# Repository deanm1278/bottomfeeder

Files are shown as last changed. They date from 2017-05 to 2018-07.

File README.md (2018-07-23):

# bottomfeeder

demo video of the synthesizer with a control panel added on top is [here](https://youtu.be/Ub5NRgZzTfE).
Note the synthesizer is mounted to the back of the panel in the video.

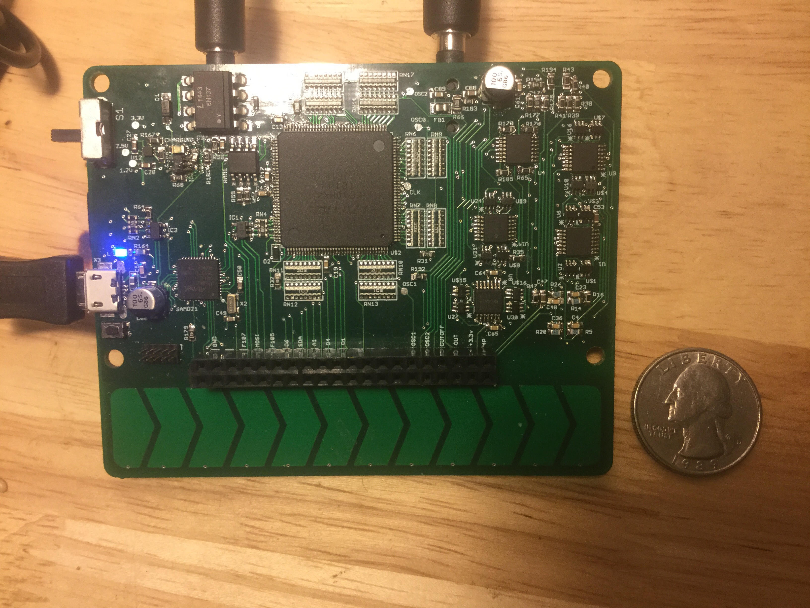
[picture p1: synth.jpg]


Features include:
- 3x 16 bit digital Wavetable Oscillators (sample rates up to 200k samples/sec)
  - Fine and coarse tuning controls for each oscillator
  - user loadable waveforms
  - 1 square wave sub oscillator for each oscillator
- Full analog 4 pole resonant low pass filter
- ADSR envelope generator mappable to filter cutoff and VCA
- Monophonic and 3 voice Paraphonic modes
- Glide rate control
- 2x LFO (also any user loadable waveform)
  - Mappable to many parameters including rate or depth of the other LFO
- Headphone output
- External input to filter
- All parameters controllable via Standard MIDI
- Header connections for modification
- Loading and saving presets
- Low cost and small form factor

## Structure
An ARM Cortex M0+ microcontroller acts as a host processor for an [FPGA-Based synthesizer](https://github.com/deanm1278/Chisel-wavetable).
The FPGA outputs the oscillators as well as PWM control voltages for the analog filter and analog VCA parameters.
[Click here](https://github.com/deanm1278/bottomfeeder/blob/master/schematics/synth_revD.pdf) to view PDF schematics.

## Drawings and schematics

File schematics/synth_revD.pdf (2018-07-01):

10k | AGND ¹⁰⁰k 100k | AGND
R180 | R178 R181 R¹⁸⁴ | R186 | R185 R¹⁸⁷ R188 R¹⁸⁹ R¹⁹⁰

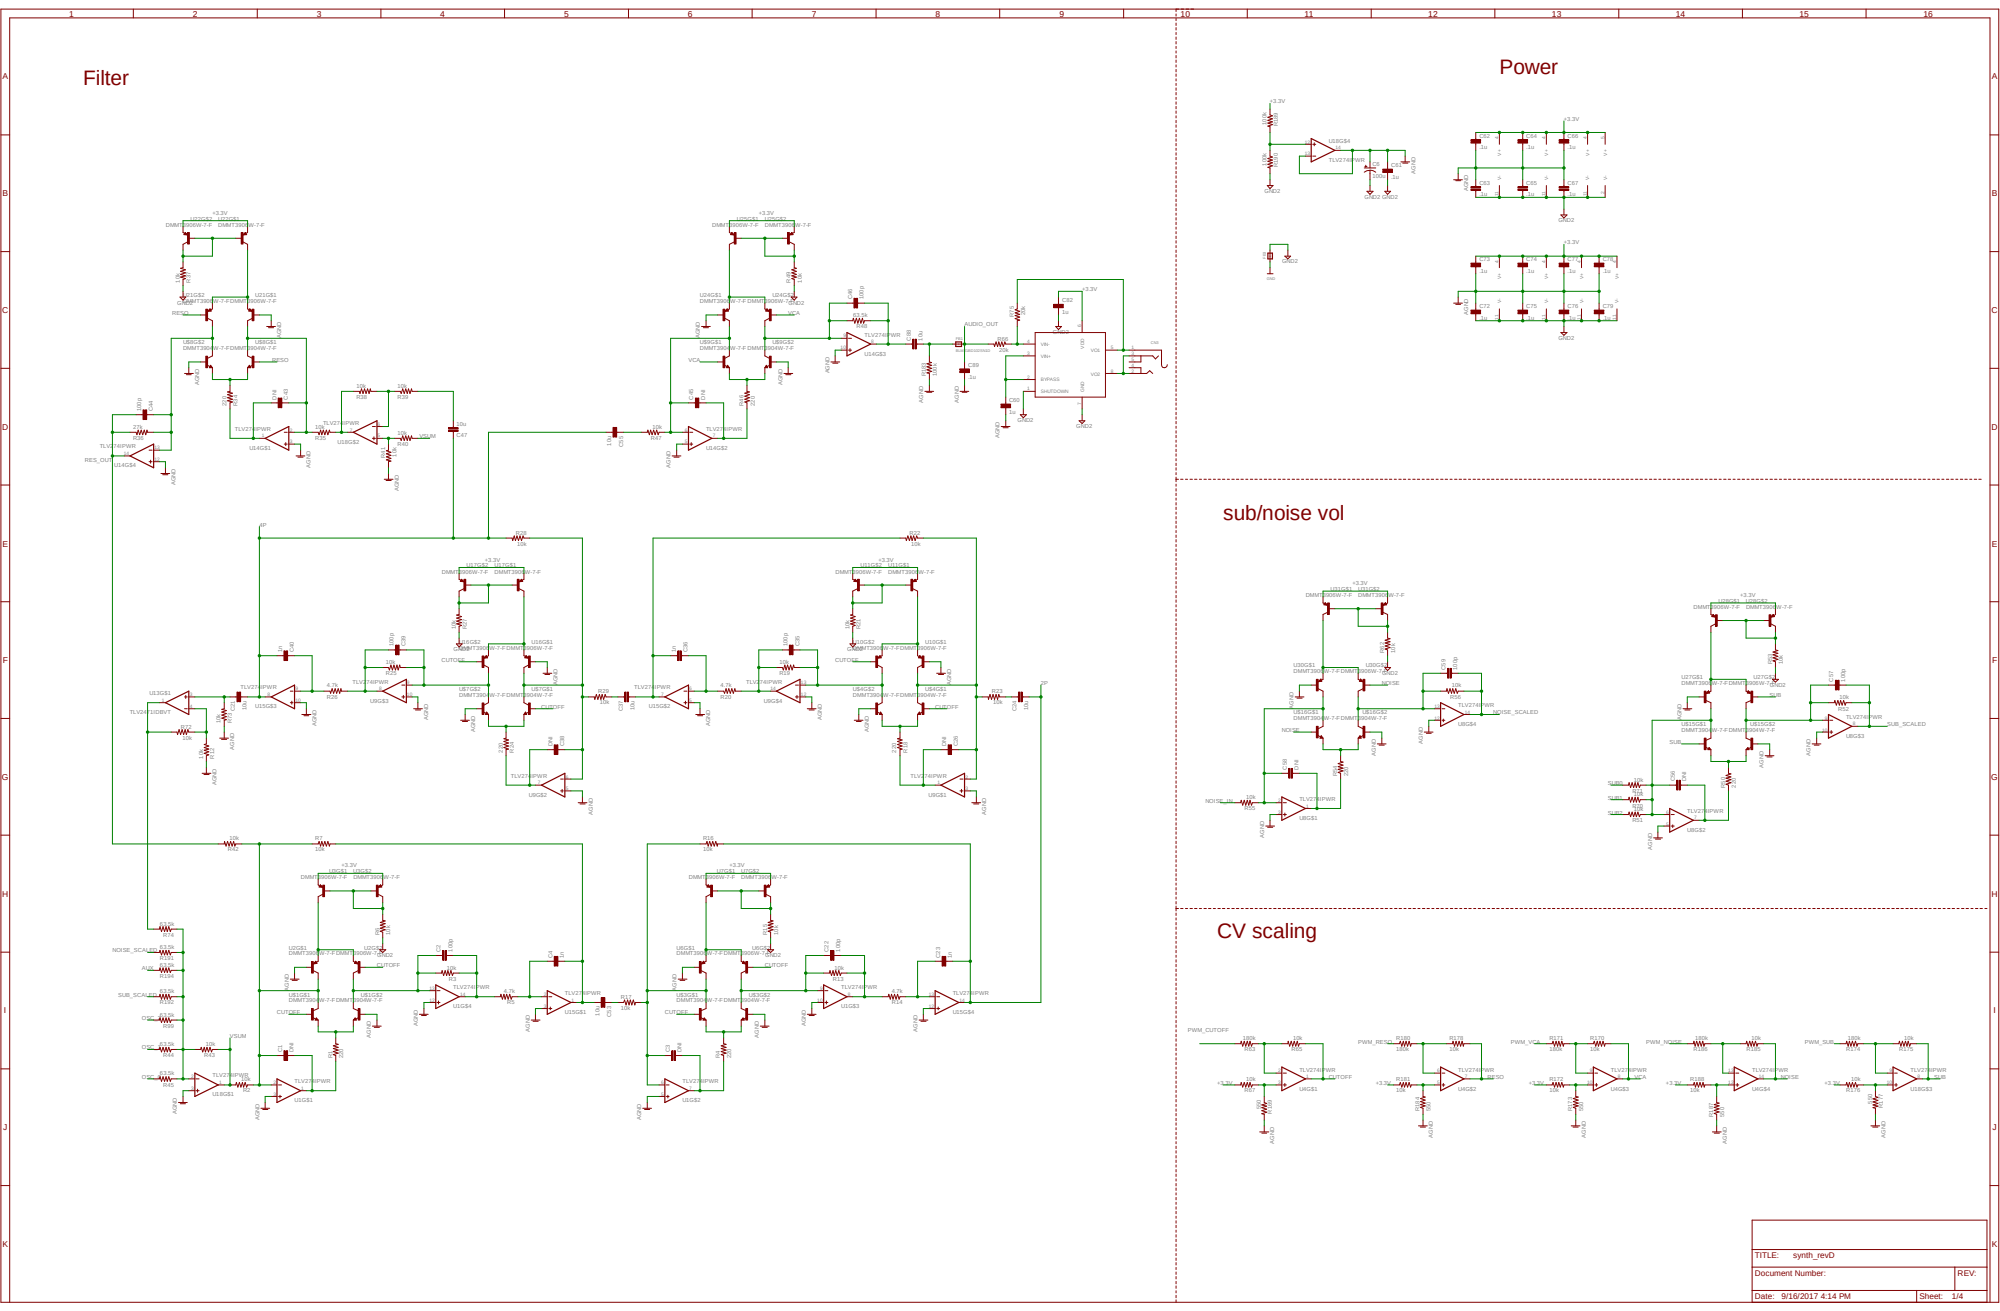
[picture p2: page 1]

IC1 | C41
8 | 9 | RN⁹A¹ ¹⁶RN⁹B² ¹⁵RN⁹C³ ¹⁴RN⁹D⁴ ¹³RN⁹E⁵ ¹²RN⁹F⁶ ¹¹RN⁹G⁷ ¹⁰RN⁹H⁸ ⁹ | RN10A

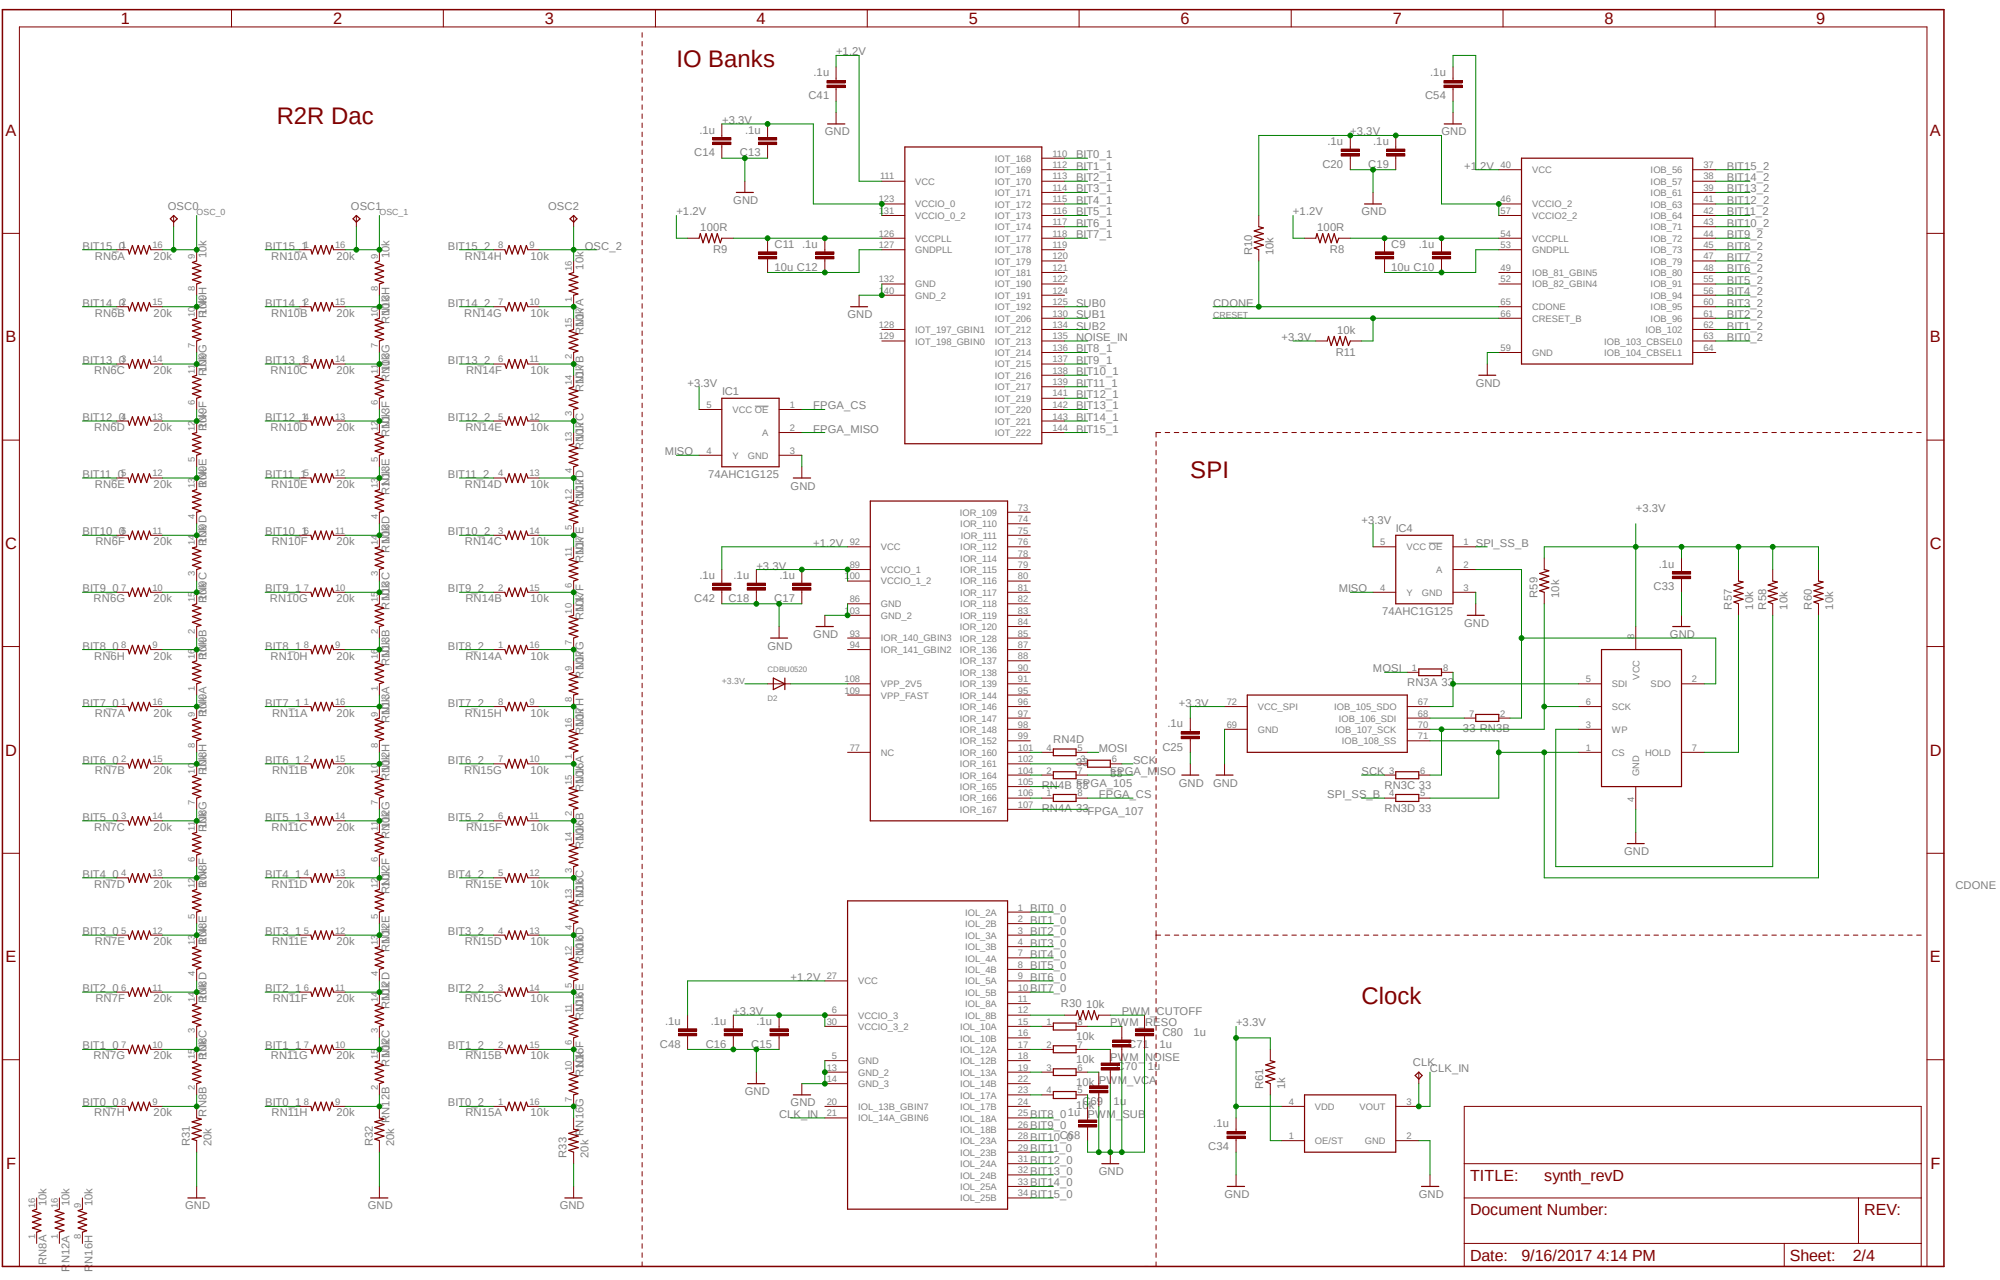
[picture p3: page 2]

# 220 GND 10k 33

# BUTTONS / LEDS

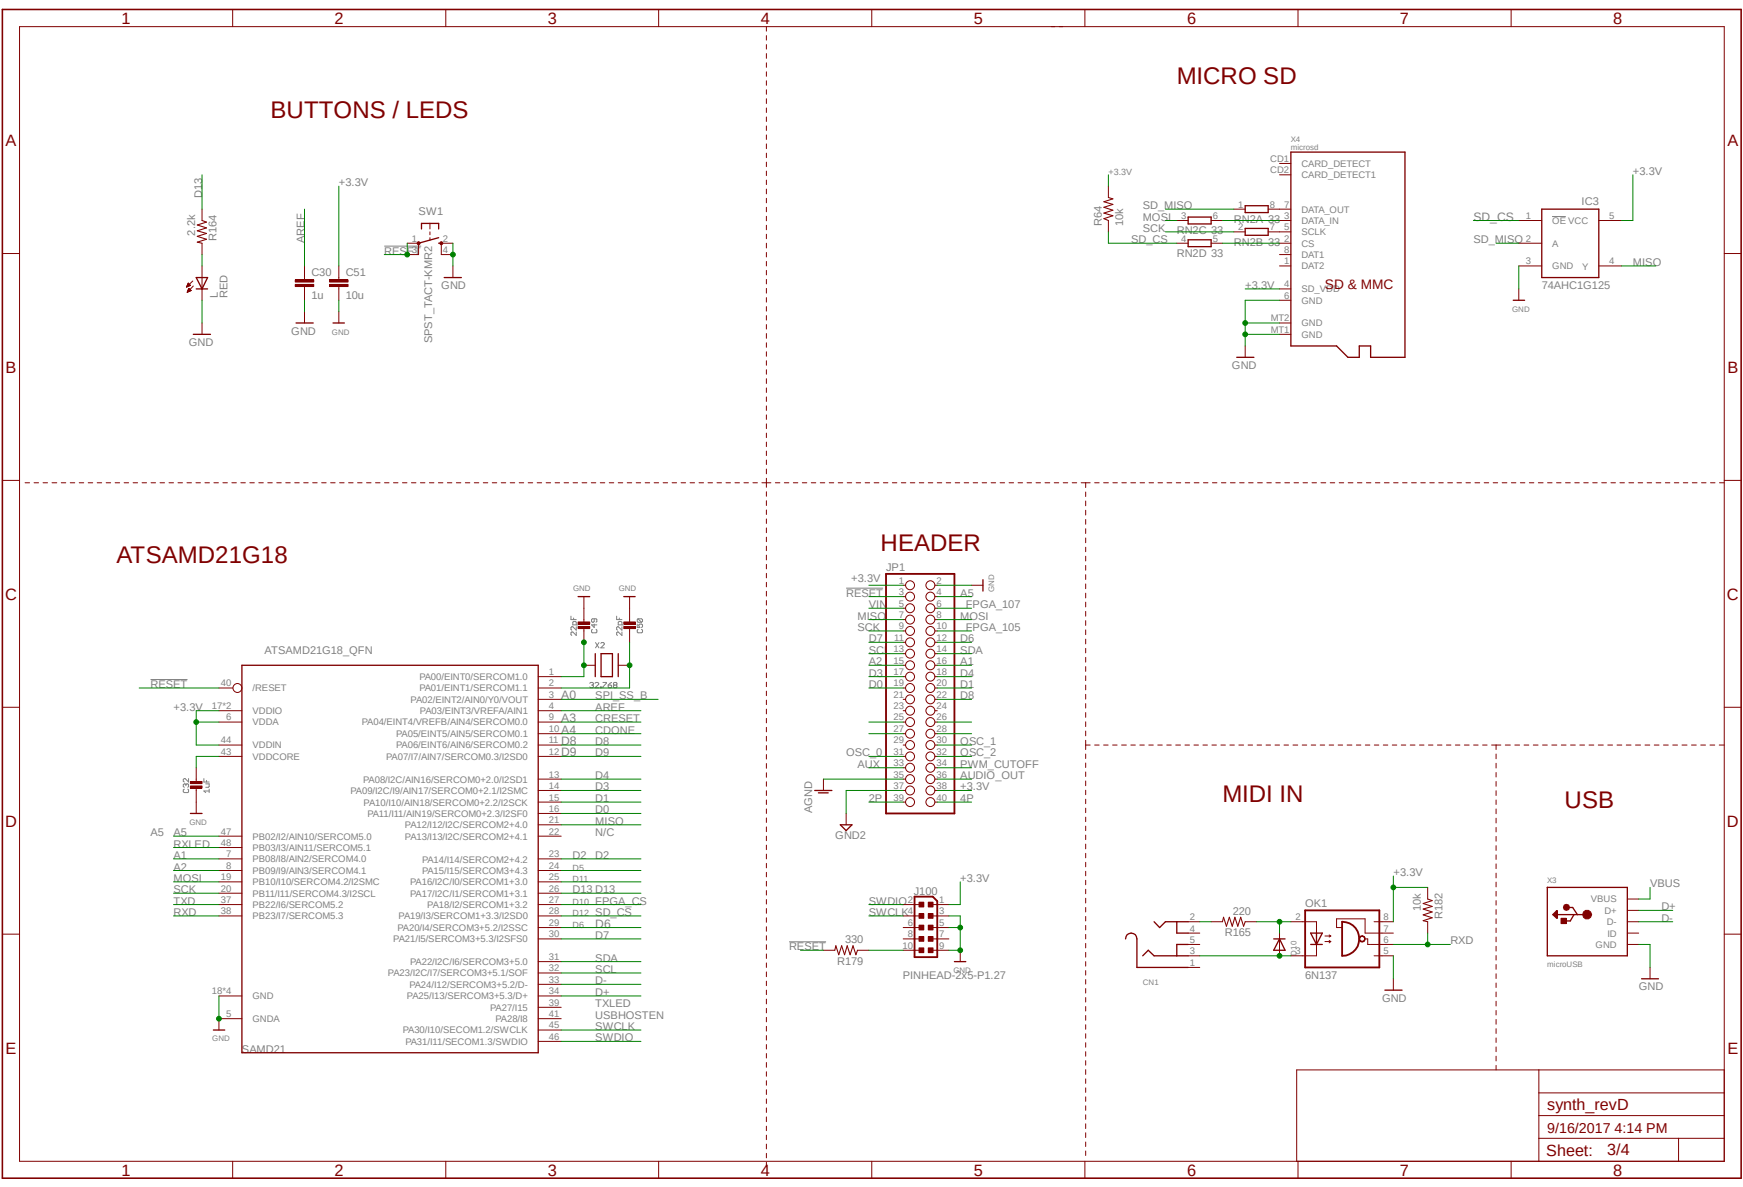
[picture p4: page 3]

CN2

2

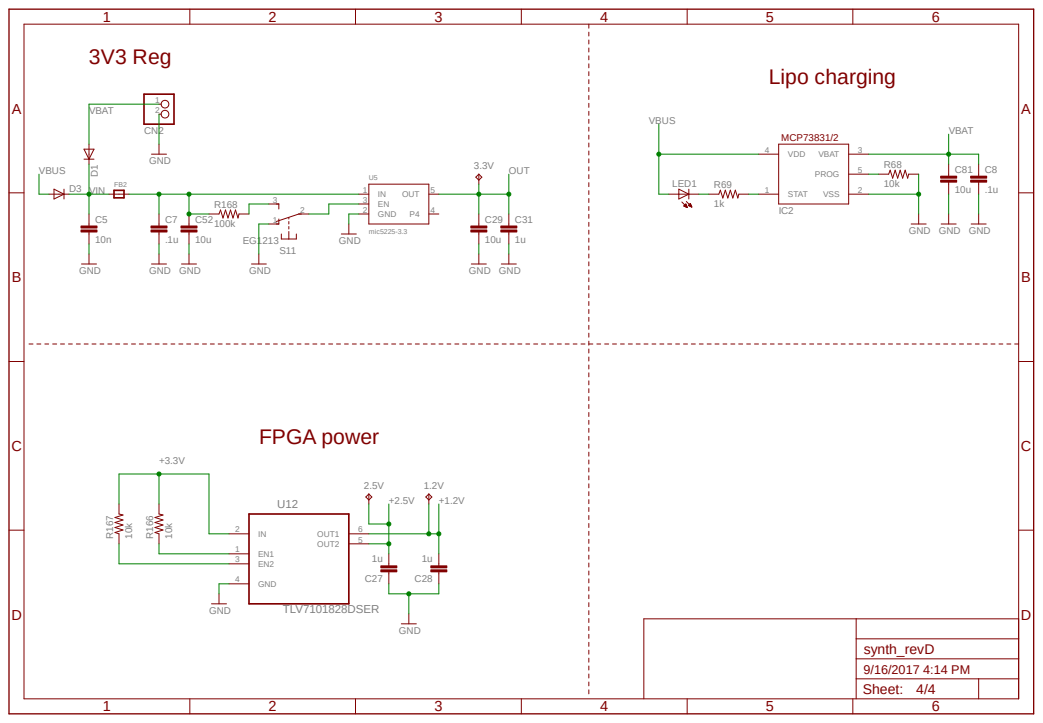
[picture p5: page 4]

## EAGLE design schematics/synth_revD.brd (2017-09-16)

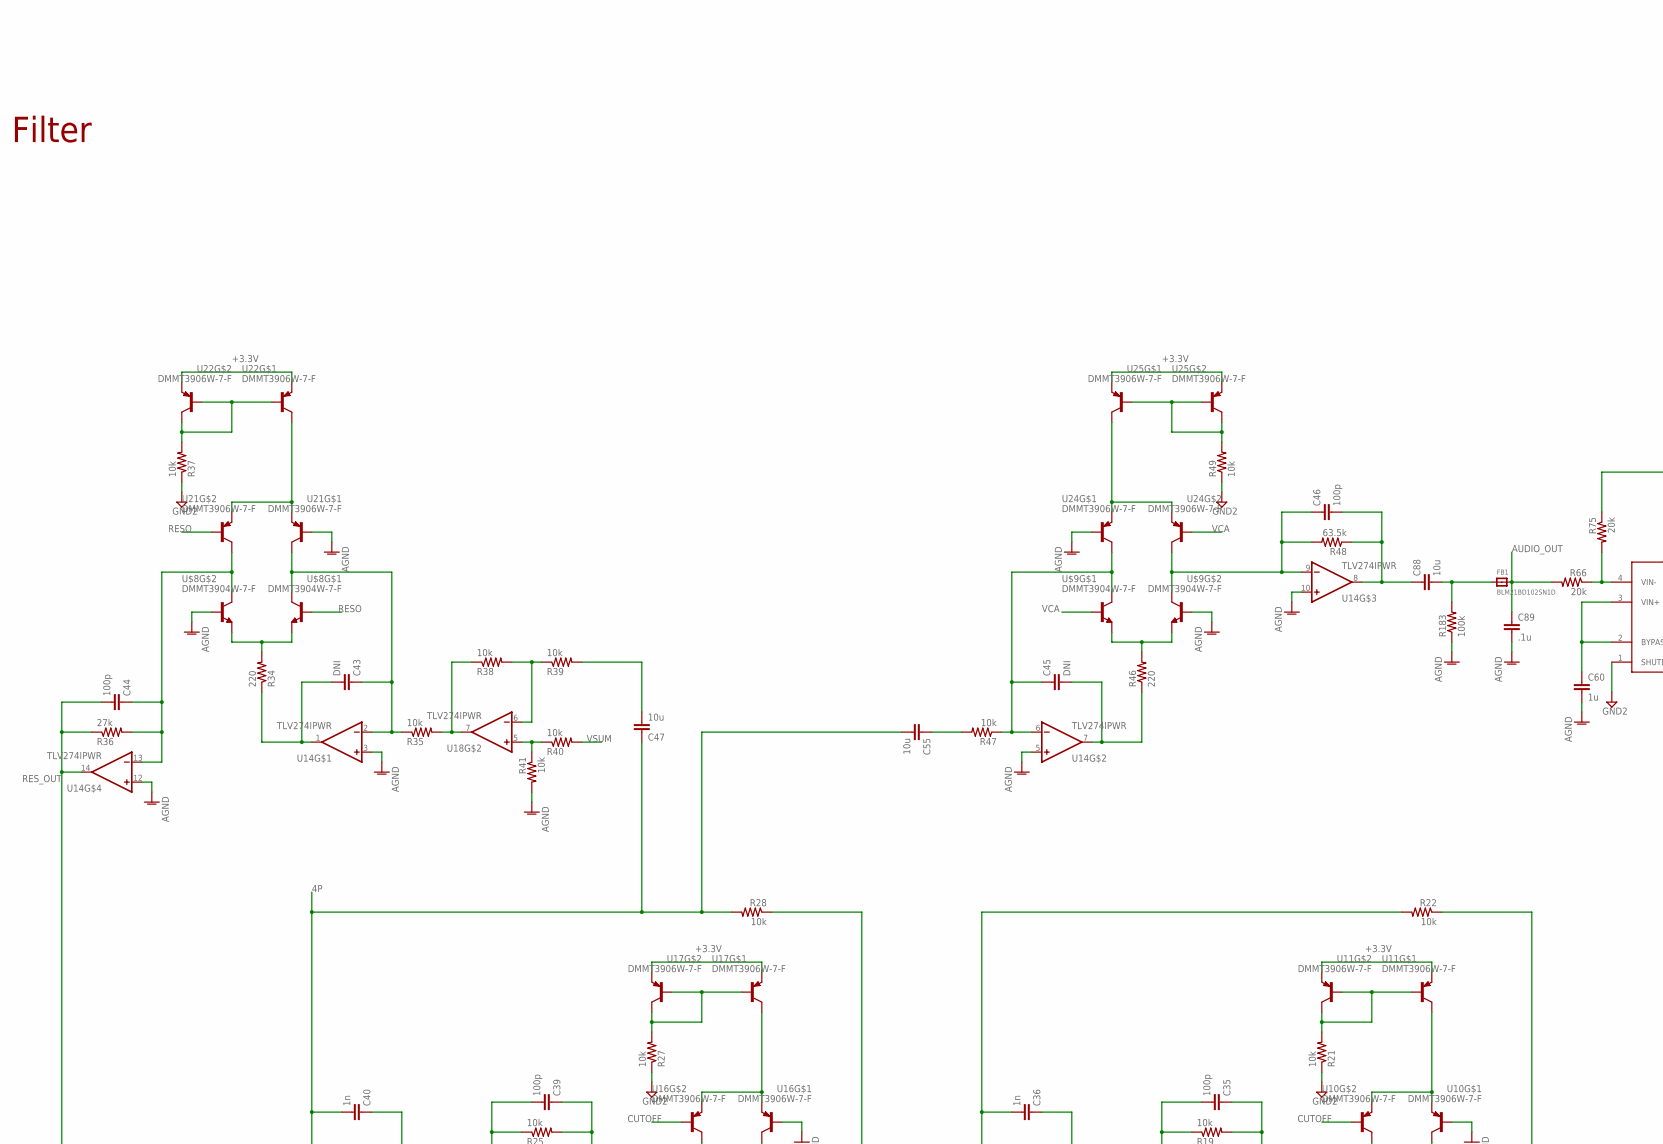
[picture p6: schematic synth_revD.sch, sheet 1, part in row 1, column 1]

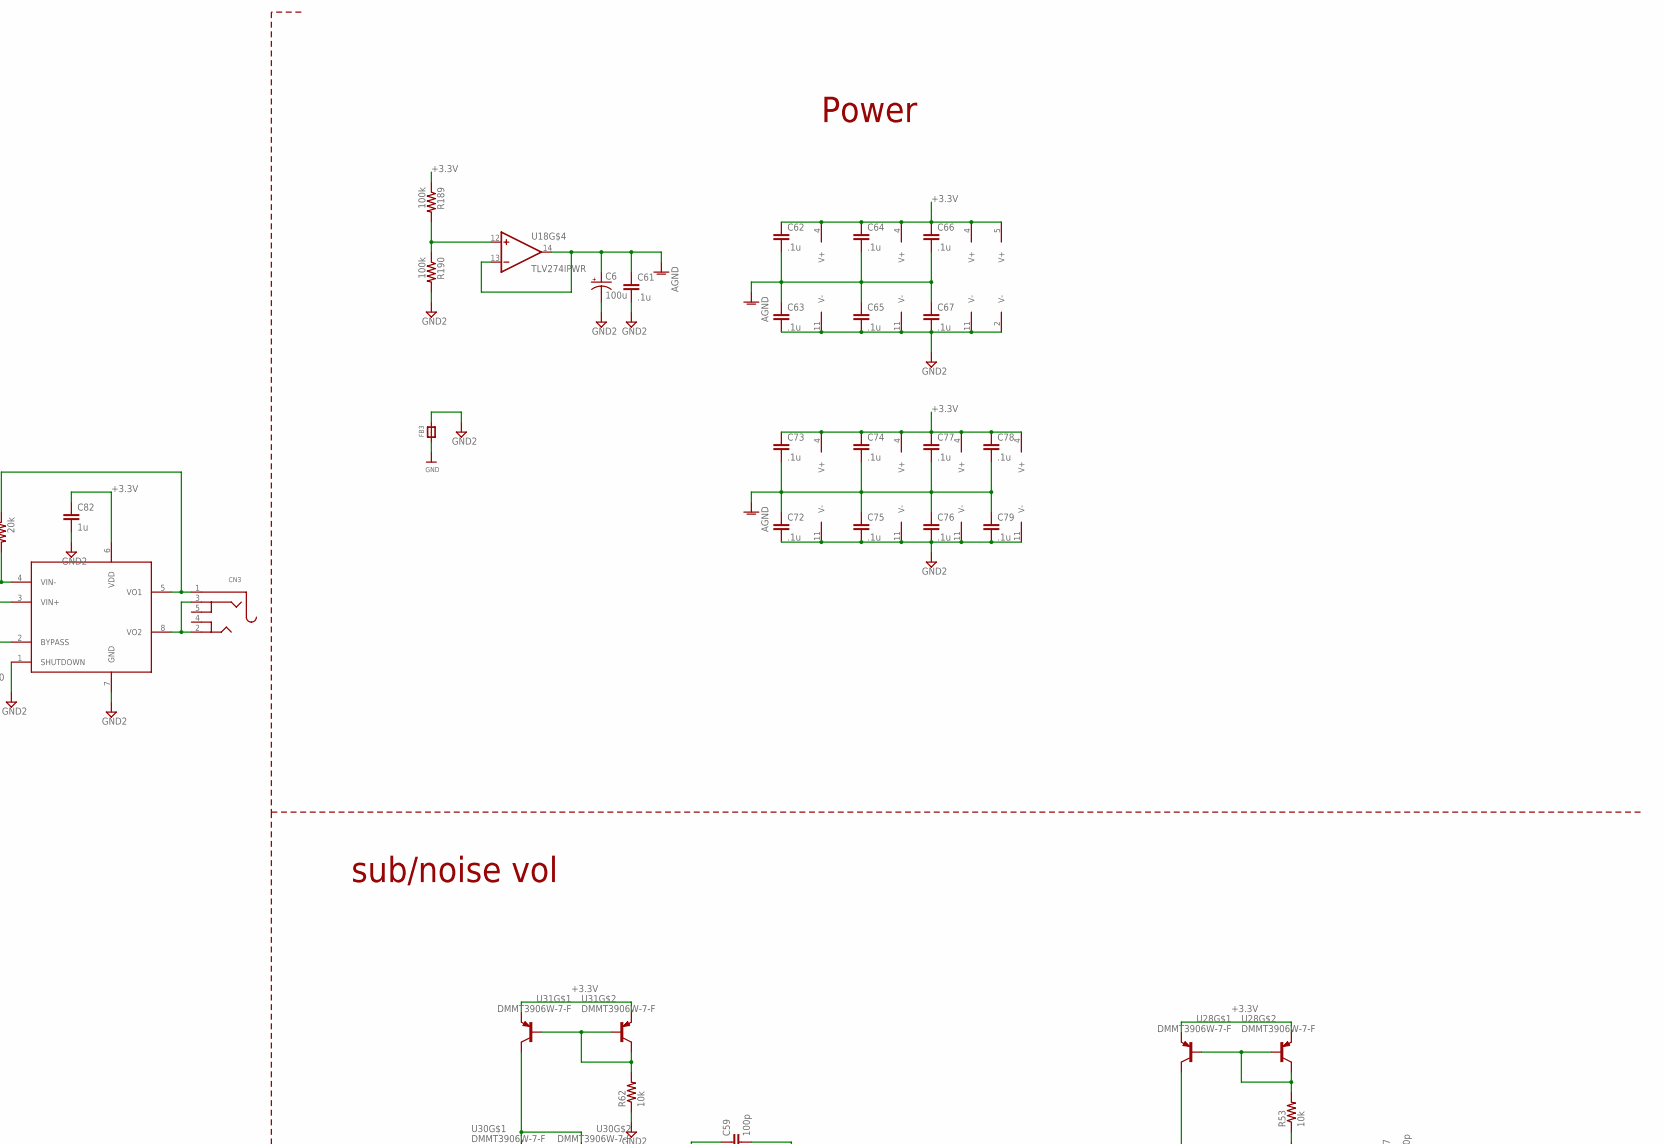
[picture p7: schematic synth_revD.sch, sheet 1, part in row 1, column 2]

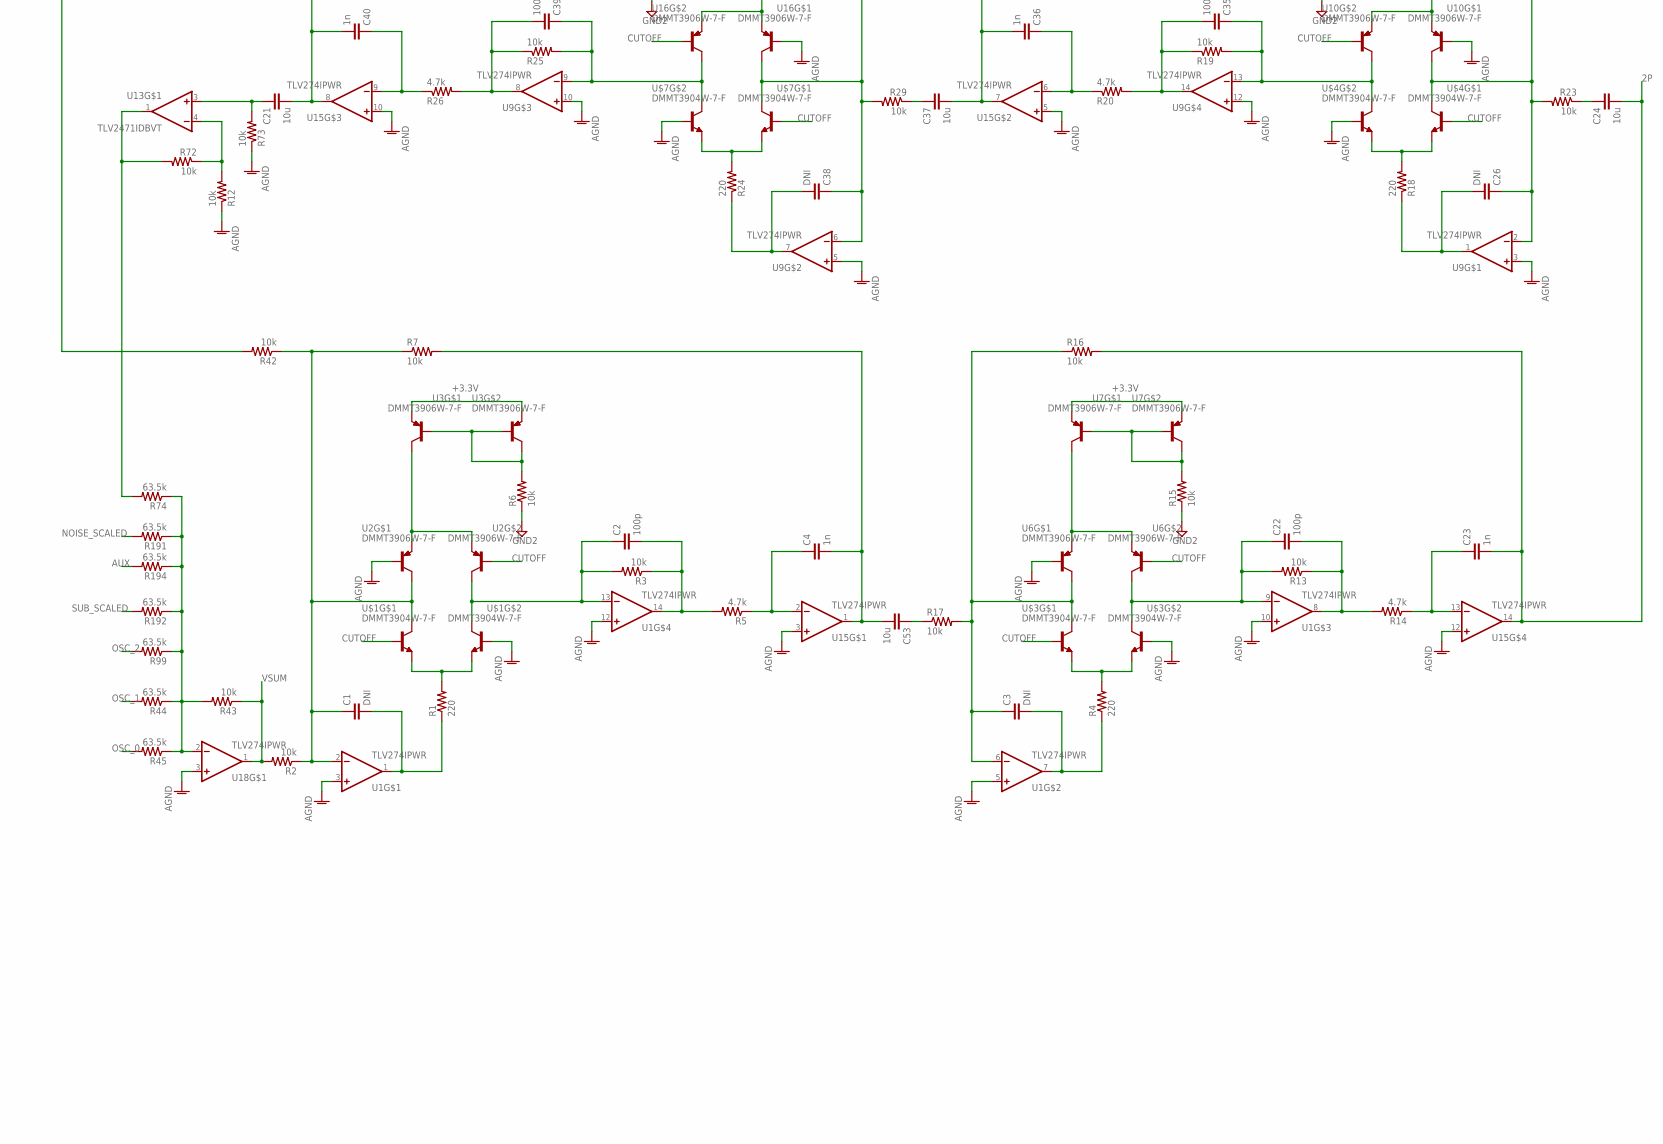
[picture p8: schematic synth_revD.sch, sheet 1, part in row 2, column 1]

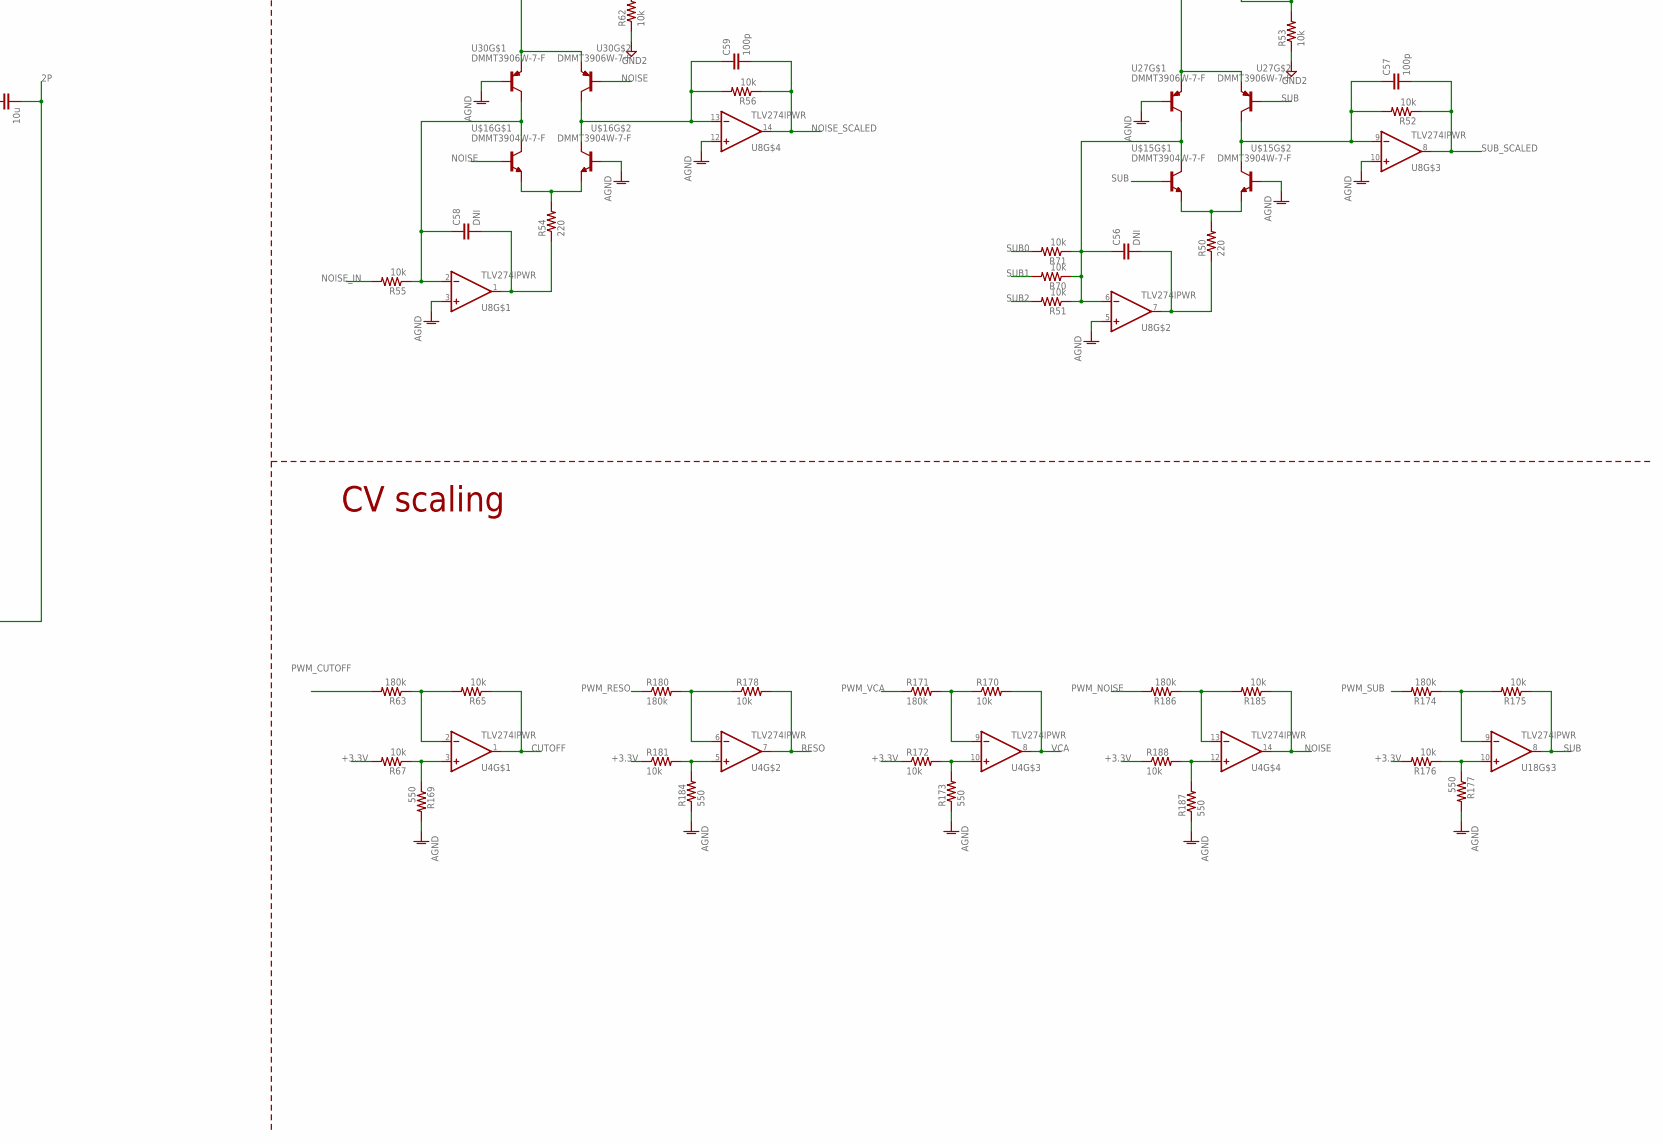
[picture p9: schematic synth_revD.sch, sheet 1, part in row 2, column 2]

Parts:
C1, C3, C26, C38, C43, C45, C56, C58: DNI; C0603
C2, C22, C35, C39, C44, C46, C57, C59: 100p; C0603
C4, C23, C36, C40: 1n; C0603
C6: 100u; PANASONIC_C
C21, C24, C37, C47, C53, C55, C88: 10u; C0603
C60, C82: 1u; C0603
C61, C62, C63, C64, C65, C66, C67, C72, C73, C74, C75, C76, C77, C78, C79, C89: .1u; C0603
CN3: AUDIO_3.5MMJACK; 4UCONN_19269
FB1: BLM21BD102SN1D; 0805
FB3: FERRITE0805; 0805
R1, R4, R18, R24, R34, R46, R50, R54: 220; R0603
R2, R3, R6, R7, R12, R13, R15, R16, R17, R19, R21, R22, R23, R25, R27, R28, R29, R35, R37, R38, R39, R40, R41, R42, R43, R47, R49, R51, R52, R53, R55, R56, R62, R65, R67, R70, R71, R72, R73, R170, R172, R175, R176, R178, R181, R185, R188: 10k; R0603
R5, R14, R20, R26: 4.7k; R0603
R36: 27k; R0603
R44, R45, R48, R74, R99, R191, R192, R194: 63.5k; R0603
R63, R171, R174, R180, R186: 180k; R0603
R66, R75: 20k; R0603
R169, R173, R177, R184, R187: 550; R0603
R183, R189, R190: 100k; R0603
U1, U4, U8, U9, U14, U15, U18: TLV274IPWR; SOP65P640X120-14N
U2, U3, U6, U7, U10, U11, U16, U17, U21, U22, U24, U25, U27, U28, U30, U31: DMMT3906W-7-F; SOT65P210X110-6N
U13: TLV2471IDBVT; SOT95P280X145-5N
U$1, U$3, U$4, U$7, U$8, U$9, U$15, U$16: DMMT3904W-7-F; SOT65P210X100-6N
U$19: LM4819MMX; SOP65P490X110-8N

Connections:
2P: C23.2, C24.2, R16.2, U15.14 (OUT); also elsewhere on the board
4P: C21.2, C40.2, C47.1, C55.2, R28.2, U15.8 (OUT); also elsewhere on the board
$P6543: C46.2, C88.1, R48.1, U14.8 (OUT)
+3.3V: C62.1, C64.1, C66.1, C73.1, C74.1, C77.1, C78.1, C82.1, R67.2, R172.1, R176.2, R181.1, R188.1, R189.1, U1.4 (V+), U3.4 (E), U3.5 (E), U4.4 (V+), U7.4 (E), U7.5 (E), U8.4 (V+), U9.4 (V+), U11.4 (E), U11.5 (E), U13.5 (V+), U14.4 (V+), U15.4 (V+), U17.4 (E), U17.5 (E), U18.4 (V+), U22.4 (E), U22.5 (E), U25.4 (E), U25.5 (E), U28.4 (E), U28.5 (E), U31.4 (E), U31.5 (E), U$19.6 (VDD); also elsewhere on the board
AGND: C6.+, C60.2, C61.1, C62.2, C63.1, C64.2, C65.1, C66.2, C67.1, C72.1, C73.2, C74.2, C75.1, C76.1, C77.2, C78.2, C79.1, C89.2, R12.1, R41.2, R73.1, R169.2, R173.1, R177.2, R183.1, R184.1, R187.1, U1.3 (+IN), U1.5 (+IN), U1.10 (+IN), U1.12 (+IN), U2.2 (B), U6.2 (B), U8.3 (+IN), U8.5 (+IN), U8.10 (+IN), U8.12 (+IN), U9.3 (+IN), U9.5 (+IN), U9.10 (+IN), U9.12 (+IN), U10.2 (B), U14.3 (+IN), U14.5 (+IN), U14.10 (+IN), U14.12 (+IN), U15.3 (+IN), U15.5 (+IN), U15.10 (+IN), U15.12 (+IN), U16.2 (B), U18.3 (+IN), U18.13 (-IN), U18.14 (OUT), U21.2 (B), U24.2 (B), U27.2 (B), U30.2 (B), U$1.1 (B), U$3.1 (B), U$4.1 (B), U$7.1 (B), U$8.1 (B), U$9.1 (B), U$15.1 (B), U$16.1 (B); also elsewhere on the board
AUDIO_OUT: C89.1, FB1.2, R66.2; also elsewhere on the board
AUX: R194.2; also elsewhere on the board
CUTOFF: R65.1, U2.1 (B), U4.1 (OUT), U6.1 (B), U10.1 (B), U16.1 (B), U$1.2 (B), U$3.2 (B), U$4.2 (B), U$7.2 (B)
GND: FB3.1; also elsewhere on the board
GND2: C6.-, C61.2, C63.2, C65.2, C67.2, C72.2, C75.2, C76.2, C79.2, C82.2, FB3.2, R6.1, R15.1, R21.1, R27.1, R37.1, R49.1, R53.1, R62.1, R190.2, U1.11 (V-), U4.11 (V-), U8.11 (V-), U9.11 (V-), U13.2 (V-), U14.11 (V-), U15.11 (V-), U18.11 (V-), U$19.1 (SHUTDOWN), U$19.7 (GND); also elsewhere on the board
unnamed: C1.1, R2.1, R7.1, R42.1, U1.2 (-IN), U2.3 (C), U$1.3 (C)
unnamed: C2.1, R3.2, U1.13 (-IN), U2.6 (C), U$1.6 (C)
unnamed: R1.2, U$1.4 (E), U$1.5 (E)
unnamed: C1.2, R1.1, U1.1 (OUT)
unnamed: R6.2, U3.1 (B), U3.2 (B), U3.6 (C)
unnamed: U2.4 (E), U2.5 (E), U3.3 (C)
unnamed: C2.2, R3.1, R5.2, U1.14 (OUT)
unnamed: C3.1, R16.1, R17.2, U1.6 (-IN), U6.3 (C), U$3.3 (C)
unnamed: C22.1, R13.2, U1.9 (-IN), U6.6 (C), U$3.6 (C)
unnamed: R4.2, U$3.4 (E), U$3.5 (E)
unnamed: C4.1, R5.1, U15.2 (-IN)
unnamed: C3.2, R4.1, U1.7 (OUT)
unnamed: C4.2, C53.2, R7.2, U15.1 (OUT)
unnamed: C21.1, R73.2, U13.3 (+IN)
unnamed: R12.2, R72.1, U13.4 (-IN)
unnamed: R72.2, R74.2, U13.1 (OUT)
unnamed: CN3.2, CN3.3, U$19.8 (VO2)
unnamed: R66.1, R75.2, U$19.4 (VIN-)
unnamed: CN3.1, R75.1, U$19.5 (VO1)
unnamed: R15.2, U7.1 (B), U7.2 (B), U7.6 (C)
unnamed: U6.4 (E), U6.5 (E), U7.3 (C)
unnamed: C22.2, R13.1, R14.2, U1.8 (OUT)
unnamed: C23.1, R14.1, U15.13 (-IN)
unnamed: C53.1, R17.1
unnamed: C26.1, R22.1, R23.2, U9.2 (-IN), U10.3 (C), U$4.3 (C)
unnamed: C35.1, R19.2, U9.13 (-IN), U10.6 (C), U$4.6 (C)
unnamed: R18.2, U$4.4 (E), U$4.5 (E)
unnamed: C26.2, R18.1, U9.1 (OUT)
unnamed: R21.2, U11.1 (B), U11.2 (B), U11.6 (C)
unnamed: U10.4 (E), U10.5 (E), U11.3 (C)
unnamed: C35.2, R19.1, R20.2, U9.14 (OUT)
unnamed: C36.1, R20.1, U15.6 (-IN)
unnamed: C36.2, C37.2, R22.2, U15.7 (OUT)
unnamed: C24.1, R23.1
unnamed: C38.1, R28.1, R29.2, U9.6 (-IN), U16.3 (C), U$7.3 (C)
unnamed: C39.1, R25.2, U9.9 (-IN), U16.6 (C), U$7.6 (C)
unnamed: R24.2, U$7.4 (E), U$7.5 (E)
unnamed: C38.2, R24.1, U9.7 (OUT)
unnamed: R27.2, U17.1 (B), U17.2 (B), U17.6 (C)
unnamed: U16.4 (E), U16.5 (E), U17.3 (C)
unnamed: C39.2, R25.1, R26.2, U9.8 (OUT)
unnamed: C40.1, R26.1, U15.9 (-IN)
unnamed: C37.1, R29.1
unnamed: C60.1, U$19.2 (BYPASS), U$19.3 (VIN+)
unnamed: C56.1, R51.1, R70.1, R71.1, U8.6 (-IN), U27.3 (C), U$15.3 (C)
unnamed: C43.1, R35.1, U14.2 (-IN), U21.3 (C), U$8.3 (C)
unnamed: R67.1, R169.1, U4.3 (+IN)
unnamed: R34.2, U$8.4 (E), U$8.5 (E)
unnamed: C43.2, R34.1, U14.1 (OUT)
unnamed: R37.2, U22.1 (B), U22.2 (B), U22.6 (C)
unnamed: U21.4 (E), U21.5 (E), U22.3 (C)
unnamed: C45.1, R47.1, U14.6 (-IN), U24.3 (C), U$9.3 (C)
unnamed: R40.1, R41.1, U18.5 (+IN)
unnamed: R35.2, R38.1, U18.7 (OUT)
unnamed: R38.2, R39.1, U18.6 (-IN)
unnamed: C46.1, R48.2, U14.9 (-IN), U24.6 (C), U$9.6 (C)
unnamed: C47.2, R39.2
unnamed: R46.2, U$9.4 (E), U$9.5 (E)
unnamed: R43.2, R44.1, R45.1, R74.1, R99.1, R191.1, R192.1, R194.1, U18.2 (-IN)
unnamed: C45.2, R46.1, U14.7 (OUT)
unnamed: C88.2, FB1.1, R183.2
unnamed: R49.2, U25.1 (B), U25.2 (B), U25.6 (C)
unnamed: U24.4 (E), U24.5 (E), U25.3 (C)
unnamed: C55.1, R47.2
unnamed: C57.1, R52.2, U8.9 (-IN), U27.6 (C), U$15.6 (C)
unnamed: R50.2, U$15.4 (E), U$15.5 (E)
unnamed: C56.2, R50.1, U8.7 (OUT)
unnamed: R53.2, U28.1 (B), U28.2 (B), U28.6 (C)
unnamed: U27.4 (E), U27.5 (E), U28.3 (C)
unnamed: C58.1, R55.1, U8.2 (-IN), U30.3 (C), U$16.3 (C)
unnamed: C59.1, R56.2, U8.13 (-IN), U30.6 (C), U$16.6 (C)
unnamed: R54.2, U$16.4 (E), U$16.5 (E)
unnamed: C58.2, R54.1, U8.1 (OUT)
unnamed: R62.2, U31.1 (B), U31.2 (B), U31.6 (C)
unnamed: U30.4 (E), U30.5 (E), U31.3 (C)
unnamed: C44.1, R36.2, U14.13 (-IN), U21.6 (C), U$8.6 (C)
unnamed: R63.1, R65.2, U4.2 (-IN)
unnamed: R176.1, R177.1, U18.10 (+IN)
unnamed: R170.1, R171.2, U4.9 (-IN)
unnamed: R174.1, R175.2, U18.9 (-IN)
unnamed: R172.2, R173.2, U4.10 (+IN)
unnamed: R185.2, R186.1, U4.13 (-IN)
unnamed: R187.2, R188.2, U4.12 (+IN)
unnamed: R181.2, R184.2, U4.5 (+IN)
unnamed: R178.1, R180.2, U4.6 (-IN)
unnamed: R189.2, R190.1, U18.12 (+IN)
NOISE: R185.1, U4.14 (OUT), U30.1 (B), U$16.2 (B)
NOISE_IN: R55.2; also elsewhere on the board
NOISE_SCALED: C59.2, R56.1, R191.2, U8.14 (OUT)
OSC_0: R45.2; also elsewhere on the board
OSC_1: R44.2; also elsewhere on the board
OSC_2: R99.2; also elsewhere on the board
PWM_CUTOFF: R63.2; also elsewhere on the board
PWM_NOISE: R186.2; also elsewhere on the board
PWM_RESO: R180.1; also elsewhere on the board
PWM_SUB: R174.2; also elsewhere on the board
PWM_VCA: R171.1; also elsewhere on the board
RESO: R178.2, U4.7 (OUT), U21.1 (B), U$8.2 (B)
RES_OUT: C44.2, R36.1, R42.2, U14.14 (OUT)
SUB: R175.1, U18.8 (OUT), U27.1 (B), U$15.2 (B)
SUB0: R71.2; also elsewhere on the board
SUB1: R70.2; also elsewhere on the board
SUB2: R51.2; also elsewhere on the board
SUB_SCALED: C57.2, R52.1, R192.2, U8.8 (OUT)
VCA: R170.2, U4.8 (OUT), U24.1 (B), U$9.2 (B)
VSUM: R2.2, R40.2, R43.1, U18.1 (OUT)

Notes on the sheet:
Filter
Power
CV scaling
sub/noise vol

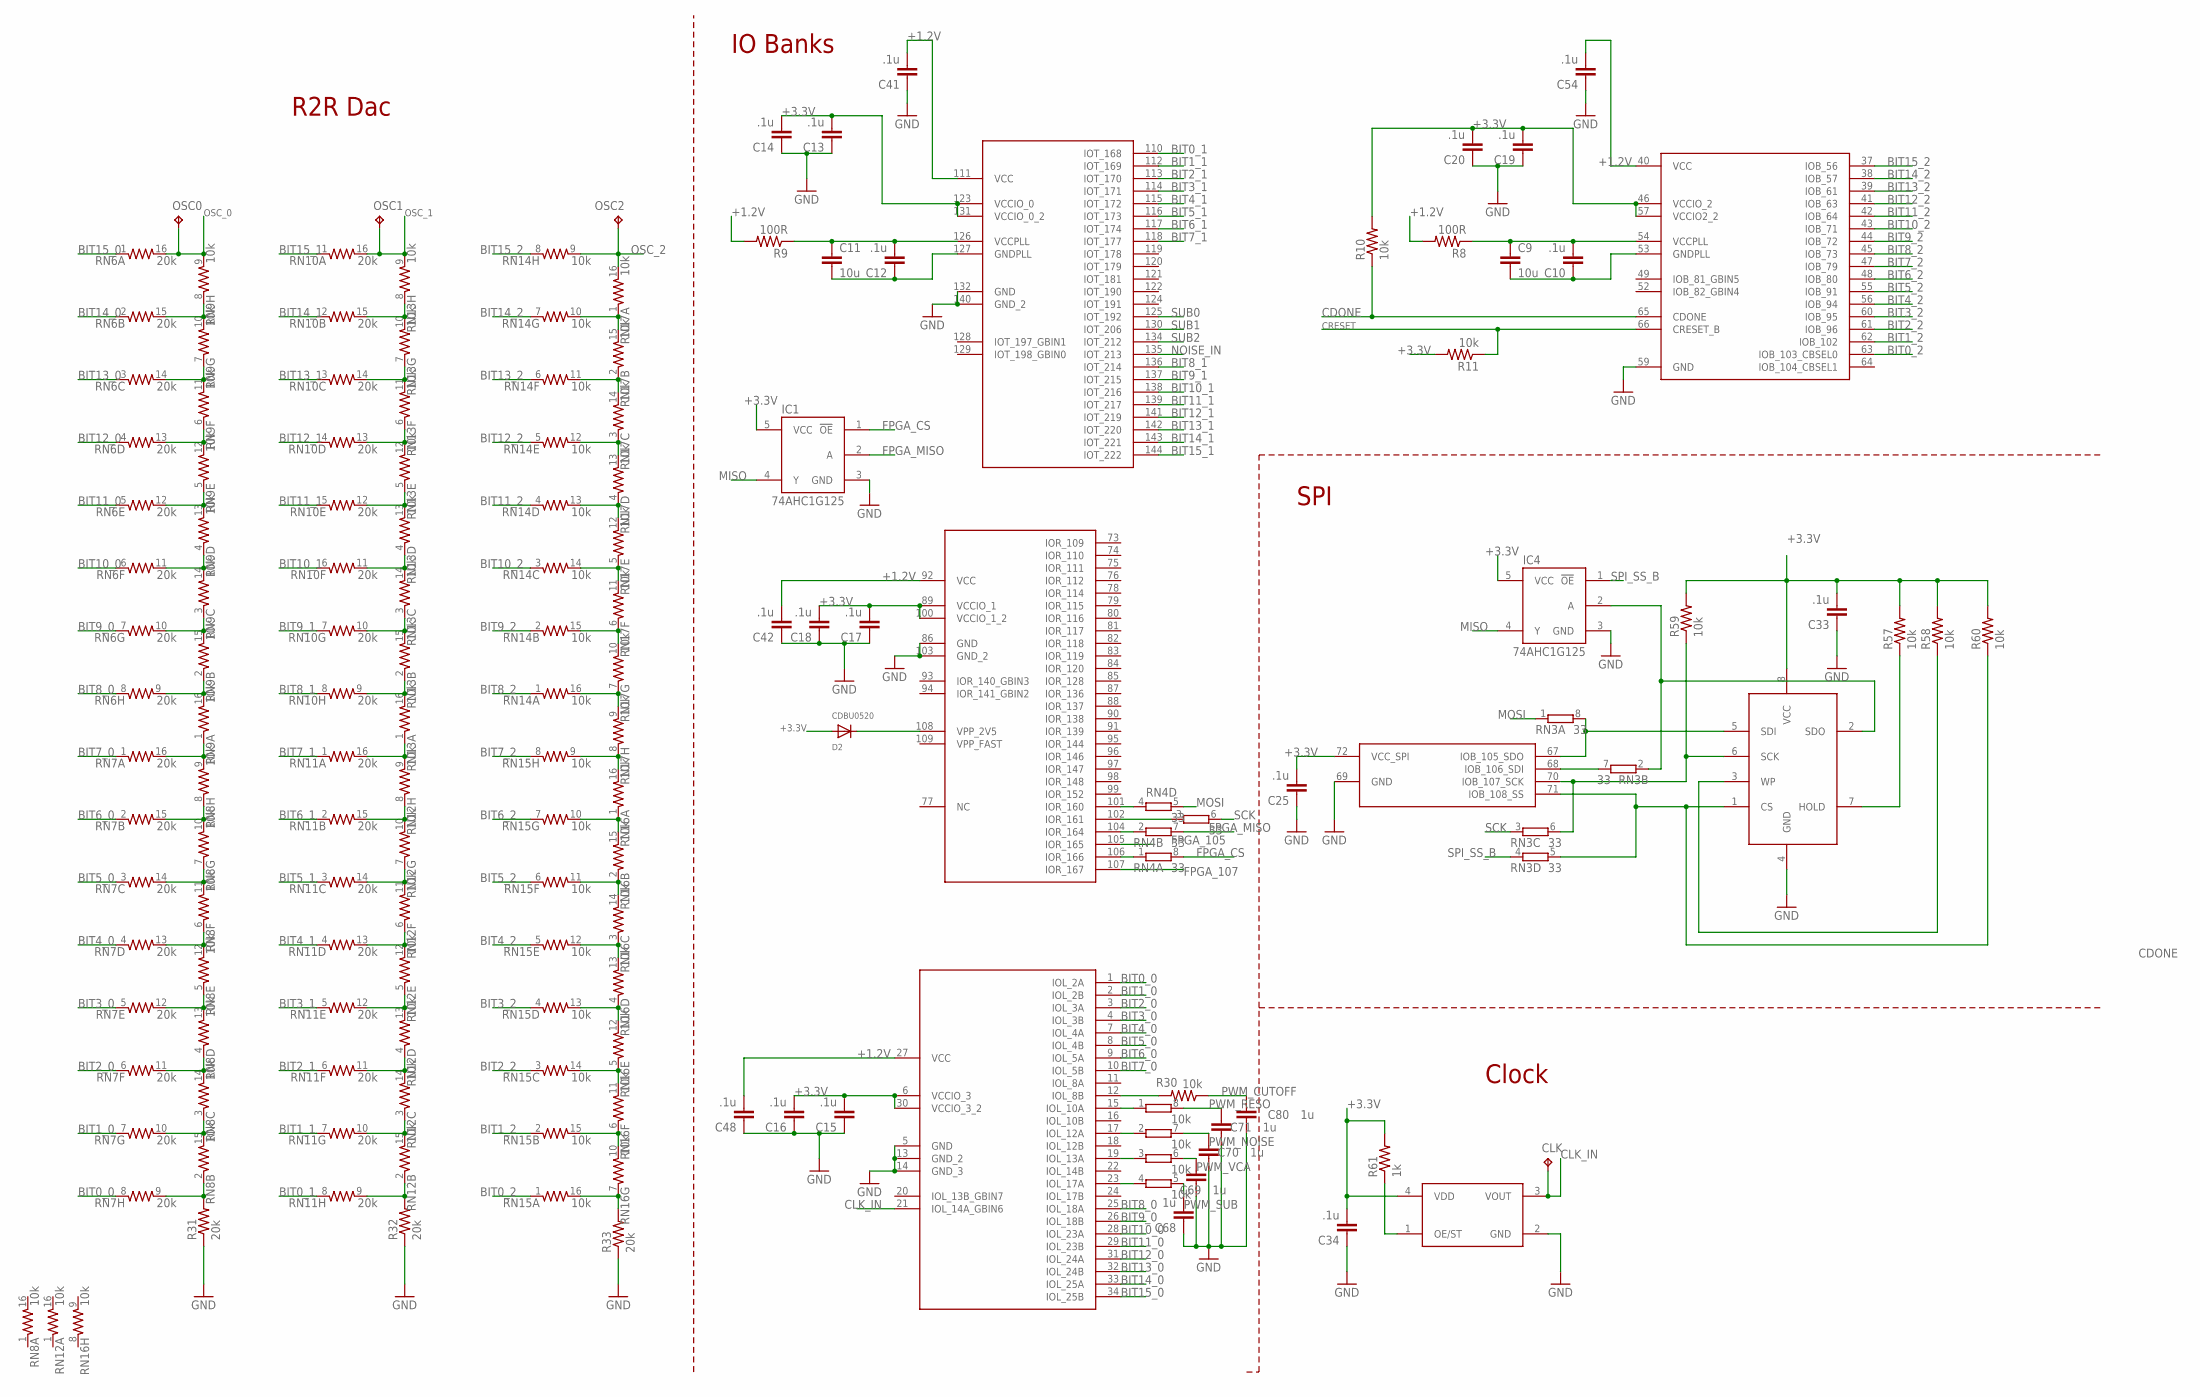
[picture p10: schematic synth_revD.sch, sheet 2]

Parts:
C9, C11: 10u; C0603
C10, C12, C13, C14, C15, C16, C17, C18, C19, C20, C25, C33, C34, C41, C42, C48, C54: .1u; C0603
C68, C69, C70, C71, C80: 1u; C0603
CLK: TPB1,27; B1,27
D2: CDBU0520; SOD-523
IC1, IC4: 74AHC1G125; SOT23-5L
OSC0, OSC1, OSC2: TPB1,27; B1,27
R8, R9: 100R; R0603
R10, R11, R30, R57, R58, R59, R60: 10k; R0603
R31, R32, R33: 20k; R0603
R61: 1k; R0603
RAM1: N25Q032A13ESC40FTR; SO08
RN3, RN4: 33; 0603-ARC
RN5: 10k; 0603-ARC
RN6, RN7, RN10, RN11: 20k; 742-16
RN8, RN9, RN12, RN13, RN14, RN15, RN16, RN17: 10k; 742-16
U$2: ICE40HX4K; TQ144
U$5: SIT1602; SMD-43.2X2.5

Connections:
$P534: R59.1, RAM1.6 (SCK), RN3.6 (2), U$2.70 (IOB_107_SCK)
$P789: R60.1, RAM1.1 (CS), RN3.5 (2), U$2.71 (IOB_108_SS)
$P3423: RAM1.5 (SDI), RN3.8 (2), U$2.67 (IOB_105_SDO)
+1.2V: C41.2, C42.2, C48.2, C54.2, R8.2, R9.2, U$2.27 (VCC), U$2.40 (VCC), U$2.92 (VCC), U$2.111 (VCC); also elsewhere on the board
+3.3V: C13.2, C14.2, C15.2, C16.2, C17.2, C18.2, C19.2, C20.2, C25.2, C33.2, C34.2, D2.A, IC1.5 (VCC), IC4.5 (VCC), R10.2, R11.2, R57.2, R58.2, R59.2, R60.2, R61.2, RAM1.8 (VCC), U$2.6 (VCCIO_3), U$2.30 (VCCIO_3_2), U$2.46 (VCCIO_2), U$2.57 (VCCIO2_2), U$2.72 (VCC_SPI), U$2.89 (VCCIO_1), U$2.100 (VCCIO_1_2), U$2.123 (VCCIO_0), U$2.131 (VCCIO_0_2), U$5.4 (VDD); also elsewhere on the board
BIT0_0: RN7.8 (1), U$2.1 (IOL_2A)
BIT0_1: RN11.8 (1), U$2.110 (IOT_168)
BIT0_2: RN15.1, U$2.63 (IOB_103_CBSEL0)
BIT1_0: RN7.7 (1), U$2.2 (IOL_2B)
BIT1_1: RN11.7 (1), U$2.112 (IOT_169)
BIT1_2: RN15.2 (1), U$2.62 (IOB_102)
BIT2_0: RN7.6 (1), U$2.3 (IOL_3A)
BIT2_1: RN11.6 (1), U$2.113 (IOT_170)
BIT2_2: RN15.3 (1), U$2.61 (IOB_96)
BIT3_0: RN7.5 (1), U$2.4 (IOL_3B)
BIT3_1: RN11.5 (1), U$2.114 (IOT_171)
BIT3_2: RN15.4 (1), U$2.60 (IOB_95)
BIT4_0: RN7.4 (1), U$2.7 (IOL_4A)
BIT4_1: RN11.4 (1), U$2.115 (IOT_172)
BIT4_2: RN15.5 (1), U$2.56 (IOB_94)
BIT5_0: RN7.3 (1), U$2.8 (IOL_4B)
BIT5_1: RN11.3 (1), U$2.116 (IOT_173)
BIT5_2: RN15.6 (1), U$2.55 (IOB_91)
BIT6_0: RN7.2 (1), U$2.9 (IOL_5A)
BIT6_1: RN11.2 (1), U$2.117 (IOT_174)
BIT6_2: RN15.7 (1), U$2.48 (IOB_80)
BIT7_0: RN7.1, U$2.10 (IOL_5B)
BIT7_1: RN11.1, U$2.118 (IOT_177)
BIT7_2: RN15.8 (1), U$2.47 (IOB_79)
BIT8_0: RN6.8 (1), U$2.25 (IOL_18A)
BIT8_1: RN10.8 (1), U$2.136 (IOT_214)
BIT8_2: RN14.1, U$2.45 (IOB_73)
BIT9_0: RN6.7 (1), U$2.26 (IOL_18B)
BIT9_1: RN10.7 (1), U$2.137 (IOT_215)
BIT9_2: RN14.2 (1), U$2.44 (IOB_72)
BIT10_0: RN6.6 (1), U$2.28 (IOL_23A)
BIT10_1: RN10.6 (1), U$2.138 (IOT_216)
BIT10_2: RN14.3 (1), U$2.43 (IOB_71)
BIT11_0: RN6.5 (1), U$2.29 (IOL_23B)
BIT11_1: RN10.5 (1), U$2.139 (IOT_217)
BIT11_2: RN14.4 (1), U$2.42 (IOB_64)
BIT12_0: RN6.4 (1), U$2.31 (IOL_24A)
BIT12_1: RN10.4 (1), U$2.141 (IOT_219)
BIT12_2: RN14.5 (1), U$2.41 (IOB_63)
BIT13_0: RN6.3 (1), U$2.32 (IOL_24B)
BIT13_1: RN10.3 (1), U$2.142 (IOT_220)
BIT13_2: RN14.6 (1), U$2.39 (IOB_61)
BIT14_0: RN6.2 (1), U$2.33 (IOL_25A)
BIT14_1: RN10.2 (1), U$2.143 (IOT_221)
BIT14_2: RN14.7 (1), U$2.38 (IOB_57)
BIT15_0: RN6.1, U$2.34 (IOL_25B)
BIT15_1: RN10.1, U$2.144 (IOT_222)
BIT15_2: RN14.8 (1), U$2.37 (IOB_56)
CDONE: R10.1, U$2.65 (CDONE); also elsewhere on the board
CLK_IN: CLK.TP, U$2.21 (IOL_14A_GBIN6), U$5.3 (VOUT)
CRESET: R11.1, U$2.66 (CRESET_B); also elsewhere on the board
FPGA_105: U$2.105 (IOR_165); also elsewhere on the board
FPGA_107: U$2.107 (IOR_167); also elsewhere on the board
FPGA_CS: IC1.1 (!OE), RN4.8 (2); also elsewhere on the board
FPGA_MISO: IC1.2 (A), RN4.7 (2)
GND: C13.1, C14.1, C15.1, C16.1, C17.1, C18.1, C19.1, C20.1, C25.1, C33.1, C34.1, C41.1, C42.1, C48.1, C54.1, C68.1, C69.1, C70.1, C71.1, C80.1, IC1.3 (GND), IC4.3 (GND), R31.1, R32.1, R33.1, RAM1.4 (GND), U$2.5 (GND), U$2.13 (GND_2), U$2.14 (GND_3), U$2.59 (GND), U$2.69 (GND), U$2.86 (GND), U$2.103 (GND_2), U$2.132 (GND), U$2.140 (GND_2), U$5.2 (GND); also elsewhere on the board
MISO: IC1.4 (Y), IC4.4 (Y); also elsewhere on the board
MOSI: RN3.1, RN4.5 (2); also elsewhere on the board
unnamed: R57.1, RAM1.7 (HOLD)
unnamed: R58.1, RAM1.3 (WP)
unnamed: R33.2, RN15.16 (2), RN16.7 (1)
unnamed: R61.1, U$5.1 (OE/ST)
unnamed: RN4.4 (1), U$2.101 (IOR_160)
unnamed: RN14.10 (2), RN17.1, RN17.15 (2)
unnamed: C9.1, C10.2, R8.1, U$2.54 (VCCPLL)
unnamed: C9.2, C10.1, U$2.53 (GNDPLL)
unnamed: C11.1, C12.2, R9.1, U$2.126 (VCCPLL)
unnamed: C11.2, C12.1, U$2.127 (GNDPLL)
unnamed: D2.K (C), U$2.108 (VPP_2V5)
unnamed: R32.2, RN11.9 (2), RN12.2 (1)
unnamed: RN15.15 (2), RN16.6 (1), RN16.10 (2)
unnamed: RN15.14 (2), RN16.5 (1), RN16.11 (2)
unnamed: RN15.13 (2), RN16.4 (1), RN16.12 (2)
unnamed: RN5.4 (1), U$2.23 (IOL_17A)
unnamed: RN3.7 (2), U$2.68 (IOB_106_SDI)
unnamed: RN15.12 (2), RN16.3 (1), RN16.13 (2)
unnamed: RN5.3 (1), U$2.19 (IOL_13A)
unnamed: RN15.11 (2), RN16.2 (1), RN16.14 (2)
unnamed: RN15.10 (2), RN16.1, RN16.15 (2)
unnamed: RN4.3 (1), U$2.102 (IOR_161)
unnamed: RN15.9 (2), RN16.16 (2), RN17.8 (1)
unnamed: RN14.16 (2), RN17.7 (1), RN17.9 (2)
unnamed: RN4.2 (1), U$2.104 (IOR_164)
unnamed: RN4.1, U$2.106 (IOR_166)
unnamed: RN14.15 (2), RN17.6 (1), RN17.10 (2)
unnamed: RN14.14 (2), RN17.5 (1), RN17.11 (2)
unnamed: RN14.13 (2), RN17.4 (1), RN17.12 (2)
unnamed: RN14.12 (2), RN17.3 (1), RN17.13 (2)
unnamed: RN14.11 (2), RN17.2 (1), RN17.14 (2)
unnamed: RN11.10 (2), RN12.3 (1), RN12.15 (2)
unnamed: RN10.15 (2), RN13.8 (1), RN13.10 (2)
unnamed: RN10.14 (2), RN13.7 (1), RN13.11 (2)
unnamed: RN10.13 (2), RN13.6 (1), RN13.12 (2)
unnamed: RN10.12 (2), RN13.5 (1), RN13.13 (2)
unnamed: RN10.11 (2), RN13.4 (1), RN13.14 (2)
unnamed: RN10.10 (2), RN13.3 (1), RN13.15 (2)
unnamed: RN10.9 (2), RN13.2 (1), RN13.16 (2)
unnamed: RN11.16 (2), RN12.9 (2), RN13.1
unnamed: RN11.15 (2), RN12.8 (1), RN12.10 (2)
unnamed: RN11.14 (2), RN12.7 (1), RN12.11 (2)
unnamed: RN11.13 (2), RN12.6 (1), RN12.12 (2)
unnamed: RN11.12 (2), RN12.5 (1), RN12.13 (2)
unnamed: RN11.11 (2), RN12.4 (1), RN12.14 (2)
unnamed: R31.2, RN7.9 (2), RN8.2 (1)
unnamed: RN7.10 (2), RN8.3 (1), RN8.15 (2)
unnamed: RN6.15 (2), RN9.8 (1), RN9.10 (2)
unnamed: RN6.14 (2), RN9.7 (1), RN9.11 (2)
unnamed: RN6.13 (2), RN9.6 (1), RN9.12 (2)
unnamed: RN6.12 (2), RN9.5 (1), RN9.13 (2)
unnamed: RN6.11 (2), RN9.4 (1), RN9.14 (2)
unnamed: RN6.10 (2), RN9.3 (1), RN9.15 (2)
unnamed: RN6.9 (2), RN9.2 (1), RN9.16 (2)
unnamed: RN7.16 (2), RN8.9 (2), RN9.1
unnamed: RN7.15 (2), RN8.8 (1), RN8.10 (2)
unnamed: RN7.14 (2), RN8.7 (1), RN8.11 (2)
unnamed: RN7.13 (2), RN8.6 (1), RN8.12 (2)
unnamed: RN7.12 (2), RN8.5 (1), RN8.13 (2)
unnamed: RN7.11 (2), RN8.4 (1), RN8.14 (2)
unnamed: RN5.2 (1), U$2.17 (IOL_12A)
unnamed: RN5.1, U$2.15 (IOL_10A)
unnamed: R30.2, U$2.12 (IOL_8B)
NOISE_IN: U$2.135 (IOT_213); also elsewhere on the board
OSC_0: OSC0.TP, RN6.16 (2), RN9.9 (2); also elsewhere on the board
OSC_1: OSC1.TP, RN10.16 (2), RN13.9 (2); also elsewhere on the board
OSC_2: OSC2.TP, RN14.9 (2), RN17.16 (2); also elsewhere on the board
PWM_CUTOFF: C80.2, R30.1; also elsewhere on the board
PWM_NOISE: C70.2, RN5.7 (2); also elsewhere on the board
PWM_RESO: C71.2, RN5.8 (2); also elsewhere on the board
PWM_SUB: C68.2, RN5.5 (2); also elsewhere on the board
PWM_VCA: C69.2, RN5.6 (2); also elsewhere on the board
SCK: RN3.3 (1), RN4.6 (2); also elsewhere on the board
SPI_SDI: IC4.2 (A), RAM1.2 (SDO), RN3.2 (1)
SPI_SS_B: IC4.1 (!OE), RN3.4 (1); also elsewhere on the board
SUB0: U$2.125 (IOT_192); also elsewhere on the board
SUB1: U$2.130 (IOT_206); also elsewhere on the board
SUB2: U$2.134 (IOT_212); also elsewhere on the board

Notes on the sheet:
R2R Dac
IO Banks
SPI
Clock

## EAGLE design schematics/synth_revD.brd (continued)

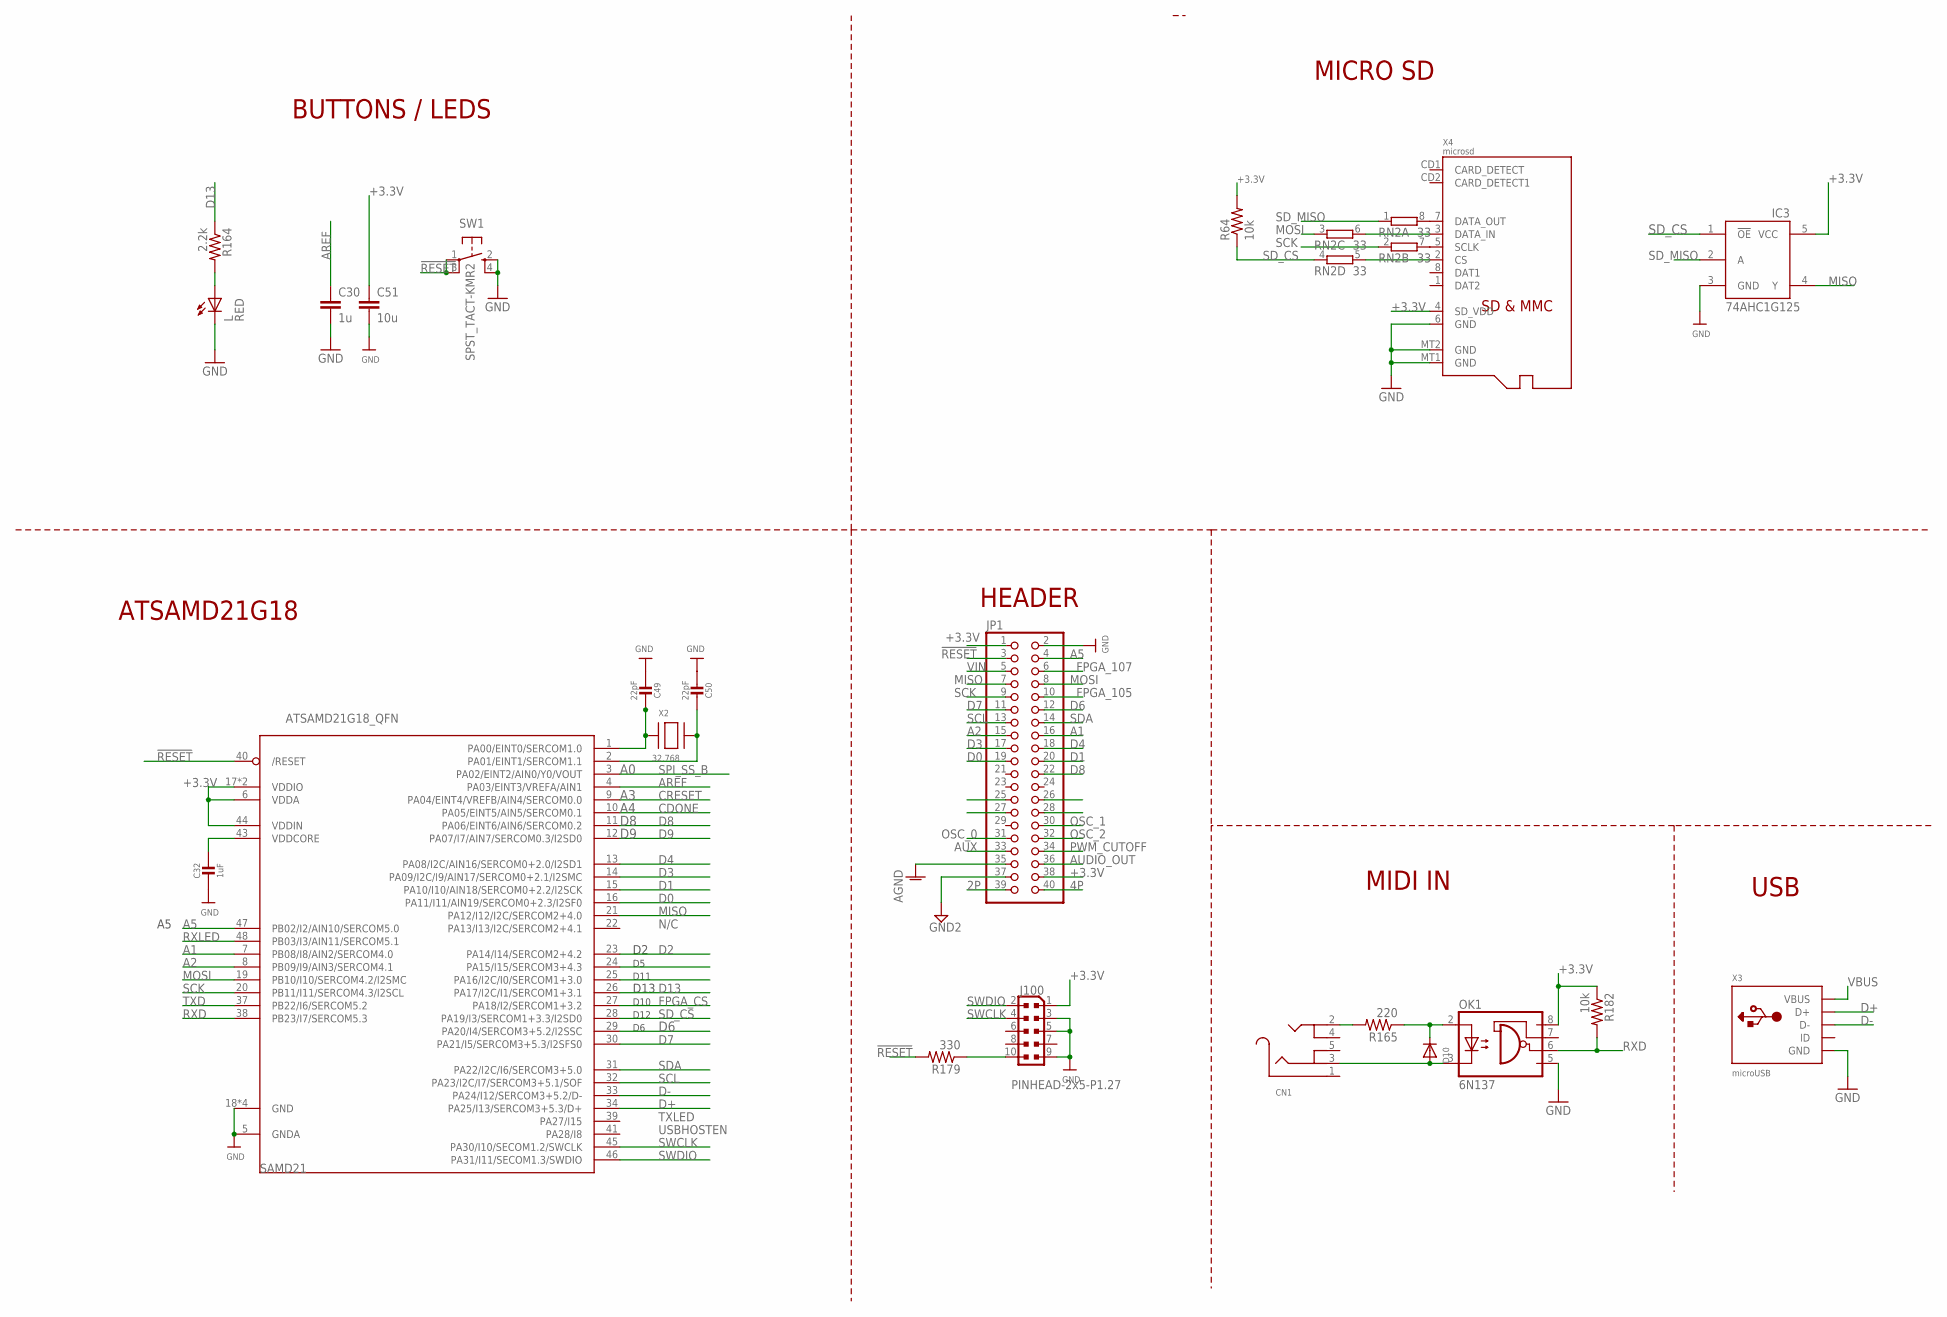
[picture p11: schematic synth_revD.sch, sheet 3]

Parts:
C30: 1u; C0603
C32: 1uF; 0603-NO
C49, C50: 22pF; 0603-NO
C51: 10u; C0603
CN1: AUDIO_3.5MMJACK; 4UCONN_19269
D10: DIODESOD-523; SOD-523
IC3: 74AHC1G125; SOT23-5L
J100: PINHEAD-2x5-P1.27; PINHEAD_2X05_127
JP1: PINHD-2X20; 2X20
L: RED; CHIP-LED0805
OK1: 6N137; DIL8-SMD
R64, R182: 10k; R0603
R164: 2.2k; R0603
R165: 220; R0603
R179: 330; R0603
RN2: 33; 0603-ARC
SAMD21: ATSAMD21G18_QFN; TQFN48_7MM
SW1: SPST_TACT-KMR2; KMR2
X2: 32.768; XTAL3215
X3: microUSB; 4UCONN_20329_V2
X4: microsd; MICROSD

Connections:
2P: JP1.39; also elsewhere on the board
4P: JP1.40; also elsewhere on the board
!RESET: JP1.3, R179.2, SAMD21.40 (/RESET), SW1.1, SW1.3 (P1)
+3.3V: C51.1, IC3.5 (VCC), J100.1, JP1.1, JP1.38, OK1.8 (VCC), R64.2, R182.1, SAMD21.6 (VDDA), SAMD21.17 (VDDIO), SAMD21.36 (VDDIO), SAMD21.44 (VDDIN), X4.4 (SD_VDD); also elsewhere on the board
A1: JP1.16, SAMD21.7 (PB08/I8/AIN2/SERCOM4.0)
A2: JP1.15, SAMD21.8 (PB09/I9/AIN3/SERCOM4.1)
A5: JP1.4, SAMD21.47 (PB02/I2/AIN10/SERCOM5.0)
AGND: JP1.35; also elsewhere on the board
AREF: C30.1, SAMD21.4 (PA03/EINT3/VREFA/AIN1)
AUDIO_OUT: JP1.36; also elsewhere on the board
AUX: JP1.33; also elsewhere on the board
CDONE: SAMD21.10 (PA05/EINT5/AIN5/SERCOM0.1); also elsewhere on the board
CRESET: SAMD21.9 (PA04/EINT4/VREFB/AIN4/SERCOM0.0); also elsewhere on the board
D0: JP1.19, SAMD21.16 (PA11/I11/AIN19/SERCOM0+2.3/I2SF0)
D1: JP1.20, SAMD21.15 (PA10/I10/AIN18/SERCOM0+2.2/I2SCK)
D2: SAMD21.23 (PA14/I14/SERCOM2+4.2)
D3: JP1.17, SAMD21.14 (PA09/I2C/I9/AIN17/SERCOM0+2.1/I2SMC)
D4: JP1.18, SAMD21.13 (PA08/I2C/AIN16/SERCOM0+2.0/I2SD1)
D6: JP1.12, SAMD21.29 (PA20/I4/SERCOM3+5.2/I2SSC)
D7: JP1.11, SAMD21.30 (PA21/I5/SERCOM3+5.3/I2SFS0)
D8: JP1.22, SAMD21.11 (PA06/EINT6/AIN6/SERCOM0.2)
D9: SAMD21.12 (PA07/I7/AIN7/SERCOM0.3/I2SD0)
D13: R164.1, SAMD21.26 (PA17/I2C/I1/SERCOM1+3.1)
D+: SAMD21.34 (PA25/I13/SERCOM3+5.3/D+), X3.D+
D-: SAMD21.33 (PA24/I12/SERCOM3+5.2/D-), X3.D-
FPGA_105: JP1.10; also elsewhere on the board
FPGA_107: JP1.6; also elsewhere on the board
FPGA_CS: SAMD21.27 (PA18/I2/SERCOM1+3.2); also elsewhere on the board
GND: C30.2, C32.2, C49.2, C50.2, C51.2, IC3.3 (GND), J100.3, J100.5, J100.9, JP1.2, L.C, OK1.5 (GND), SAMD21.5 (GNDA), SAMD21.18 (GND), SAMD21.35 (GND), SAMD21.42 (GND), SAMD21.THERMAL (GND), SW1.2 (S), SW1.4 (S1), X3.BASE@1 (GND), X3.BASE@2 (GND), X3.GND, X3.SPRT@1 (GND), X3.SPRT@2 (GND), X3.SPRT@3 (GND), X3.SPRT@4 (GND), X4.6 (GND), X4.MT1 (GND), X4.MT2 (GND); also elsewhere on the board
GND2: JP1.37; also elsewhere on the board
MISO: IC3.4 (Y), JP1.7, SAMD21.21 (PA12/I12/I2C/SERCOM2+4.0); also elsewhere on the board
MOSI: JP1.8, RN2.3 (1), SAMD21.19 (PB10/I10/SERCOM4.2/I2SMC); also elsewhere on the board
unnamed: CN1.2, R165.2
unnamed: J100.10, R179.1
unnamed: RN2.8 (2), X4.7 (DATA_OUT)
unnamed: RN2.7 (2), X4.5 (SCLK)
unnamed: RN2.6 (2), X4.3 (DATA_IN)
unnamed: RN2.5 (2), X4.2 (CS)
unnamed: L.A, R164.2
unnamed: C49.1, SAMD21.1 (PA00/EINT0/SERCOM1.0), X2.P$1
unnamed: C50.1, SAMD21.2 (PA01/EINT1/SERCOM1.1), X2.P$2
unnamed: D10.K (C), OK1.2 (A), R165.1
unnamed: CN1.3, D10.A, OK1.3 (C)
OSC_0: JP1.31; also elsewhere on the board
OSC_1: JP1.30; also elsewhere on the board
OSC_2: JP1.32; also elsewhere on the board
PWM_CUTOFF: JP1.34; also elsewhere on the board
RXD: OK1.6 (VO), R182.2, SAMD21.38 (PB23/I7/SERCOM5.3)
RXLED: SAMD21.48 (PB03/I3/AIN11/SERCOM5.1)
SCK: JP1.9, RN2.2 (1), SAMD21.20 (PB11/I11/SERCOM4.3/I2SCL); also elsewhere on the board
SCL: JP1.13, SAMD21.32 (PA23/I2C/I7/SERCOM3+5.1/SOF)
SDA: JP1.14, SAMD21.31 (PA22/I2C/I6/SERCOM3+5.0)
SD_CS: IC3.1 (!OE), R64.1, RN2.4 (1), SAMD21.28 (PA19/I3/SERCOM1+3.3/I2SD0)
SD_MISO: IC3.2 (A), RN2.1
SPI_SS_B: SAMD21.3 (PA02/EINT2/AIN0/Y0/VOUT); also elsewhere on the board
SWCLK: J100.4, SAMD21.45 (PA30/I10/SECOM1.2/SWCLK)
SWDIO: J100.2, SAMD21.46 (PA31/I11/SECOM1.3/SWDIO)
TXD: SAMD21.37 (PB22/I6/SERCOM5.2)
VBUS: X3.VBUS; also elsewhere on the board
VDDCORE1: C32.1, SAMD21.43 (VDDCORE)
VIN: JP1.5; also elsewhere on the board

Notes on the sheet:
N/C
TXLED
USBHOSTEN
RXLED
TXD
RXD
D12
D10
D11
D13
ATSAMD21G18
BUTTONS / LEDS
MICRO SD
USB
HEADER
MIDI IN

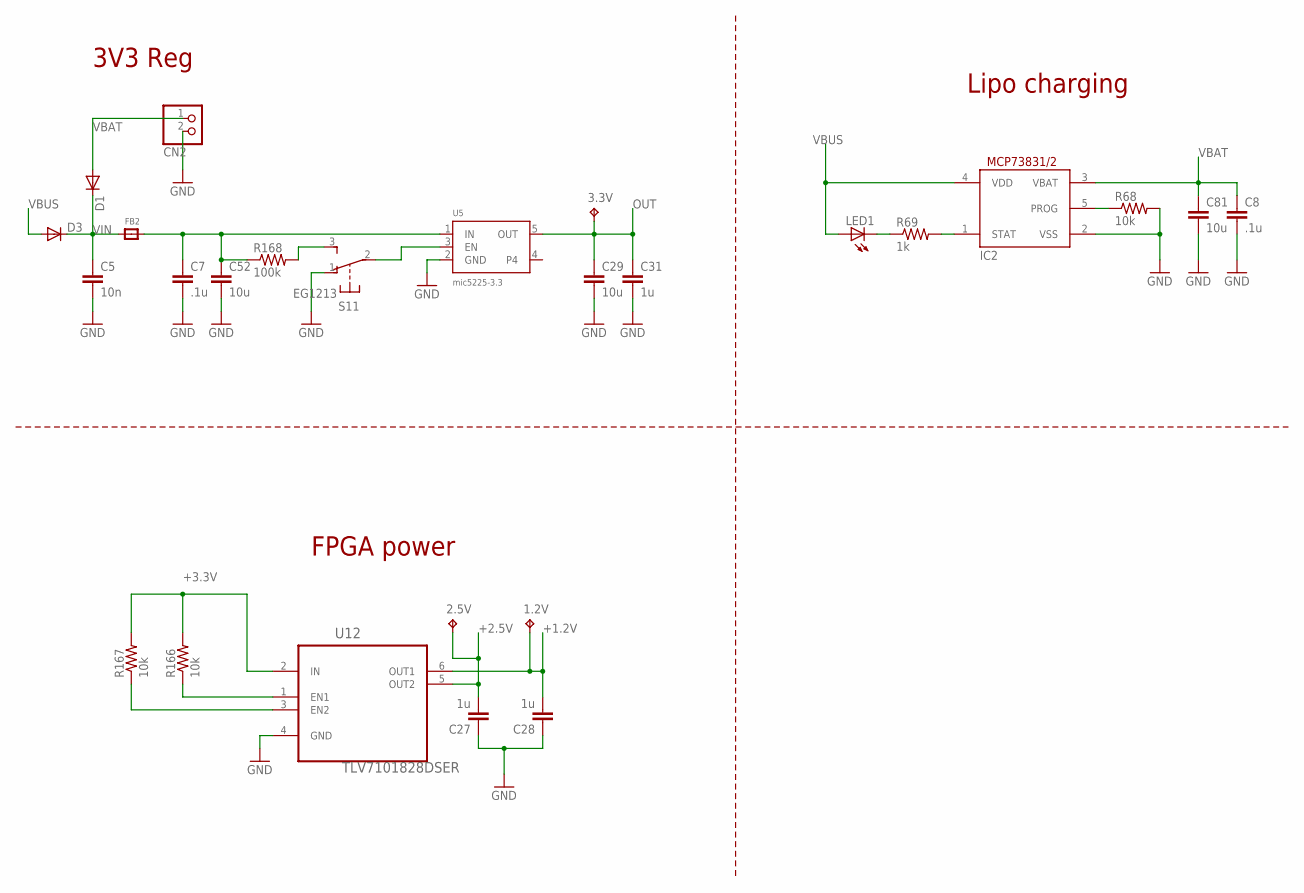
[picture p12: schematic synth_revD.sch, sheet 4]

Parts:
1.2V, 2.5V, 3.3V: TPB1,27; B1,27
C5: 10n; C0603
C7, C8: .1u; C0603
C27, C28, C31: 1u; C0603
C29, C52, C81: 10u; C0603
CN2: JST_2PIN-SMT-RA; JST-PH-2-SMT-RA
D1, D3: DIODE-SOD123; SOD123
FB2: FERRITE; 0603
IC2: MCP73831/OT; SOT23-5L
LED1: LEDCHIP-LED0805; CHIP-LED0805
R68, R166, R167: 10k; R0603
R69: 1k; R0603
R168: 100k; R0603
S1: EG1213
U5: mic5225-3.3; SOT23-5
U12: TLV7101828DSER; SON50P150X150X80-6N

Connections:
$P9999: C7.1, C52.1, FB2.2, R168.1, U5.1 (IN)
+1.2V: 1.2V.TP, C28.2, U12.6 (OUT1); also elsewhere on the board
+2.5V: 2.5V.TP, C27.2, U12.5 (OUT2)
+3.3V: R166.2, R167.2, U12.2 (IN); also elsewhere on the board
GND: C5.2, C7.2, C8.2, C27.1, C28.1, C29.2, C31.2, C52.2, C81.2, CN2.2 (1), IC2.2 (VSS), R68.2, S1.1 (O), U5.2 (GND), U12.4 (GND); also elsewhere on the board
unnamed: R168.2, S1.3 (S)
unnamed: IC2.5 (PROG), R68.1
unnamed: S1.2, U5.3 (EN)
unnamed: IC2.1 (STAT), R69.2
unnamed: LED1.C, R69.1
unnamed: R166.1, U12.1 (EN1)
unnamed: R167.1, U12.3 (EN2)
OUT: 3.3V.TP, C29.1, C31.1, U5.5 (OUT)
VBAT: C8.1, C81.1, CN2.1 (2), D1.A, IC2.3 (VBAT)
VBUS: D3.A, IC2.4 (VDD), LED1.A; also elsewhere on the board
VIN: C5.1, D1.C, D3.C, FB2.1; also elsewhere on the board

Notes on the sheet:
FPGA power
3V3 Reg
Lipo charging

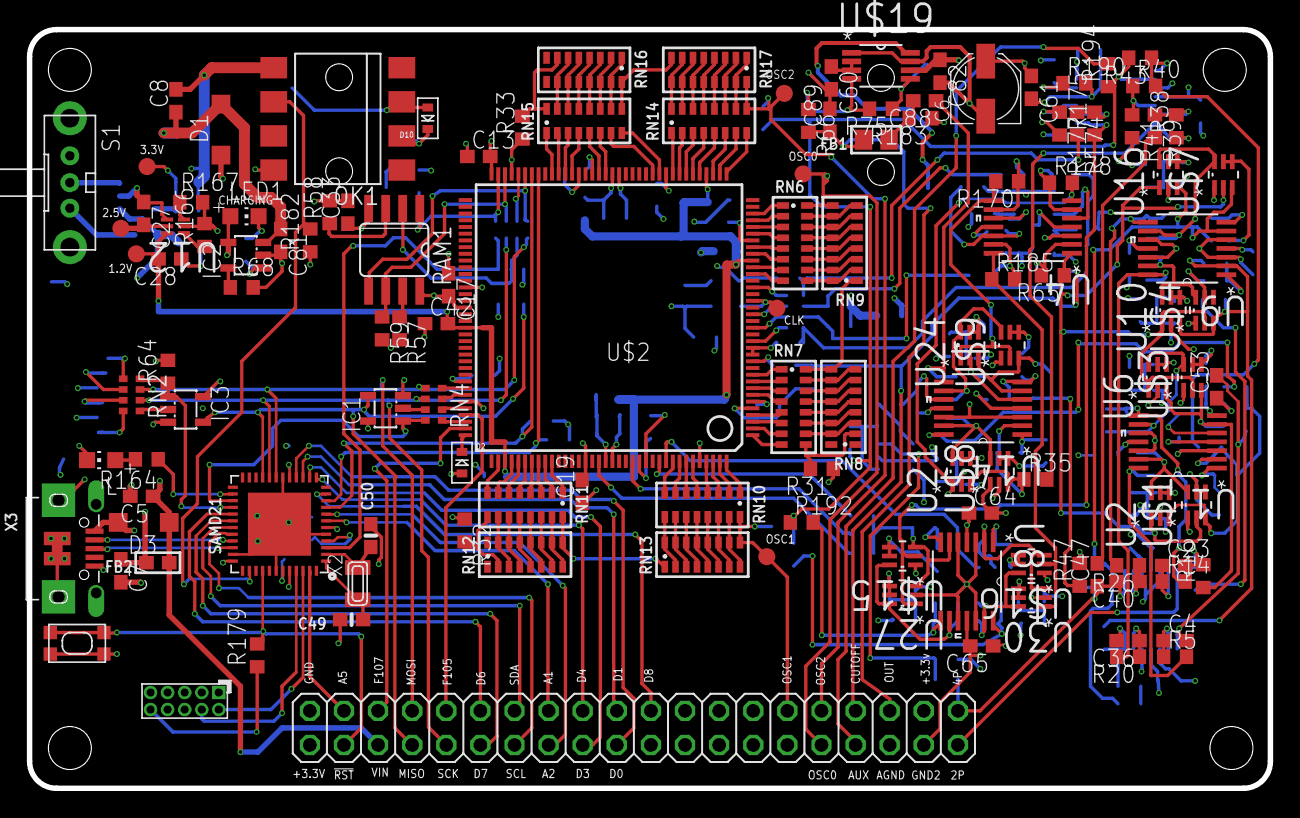
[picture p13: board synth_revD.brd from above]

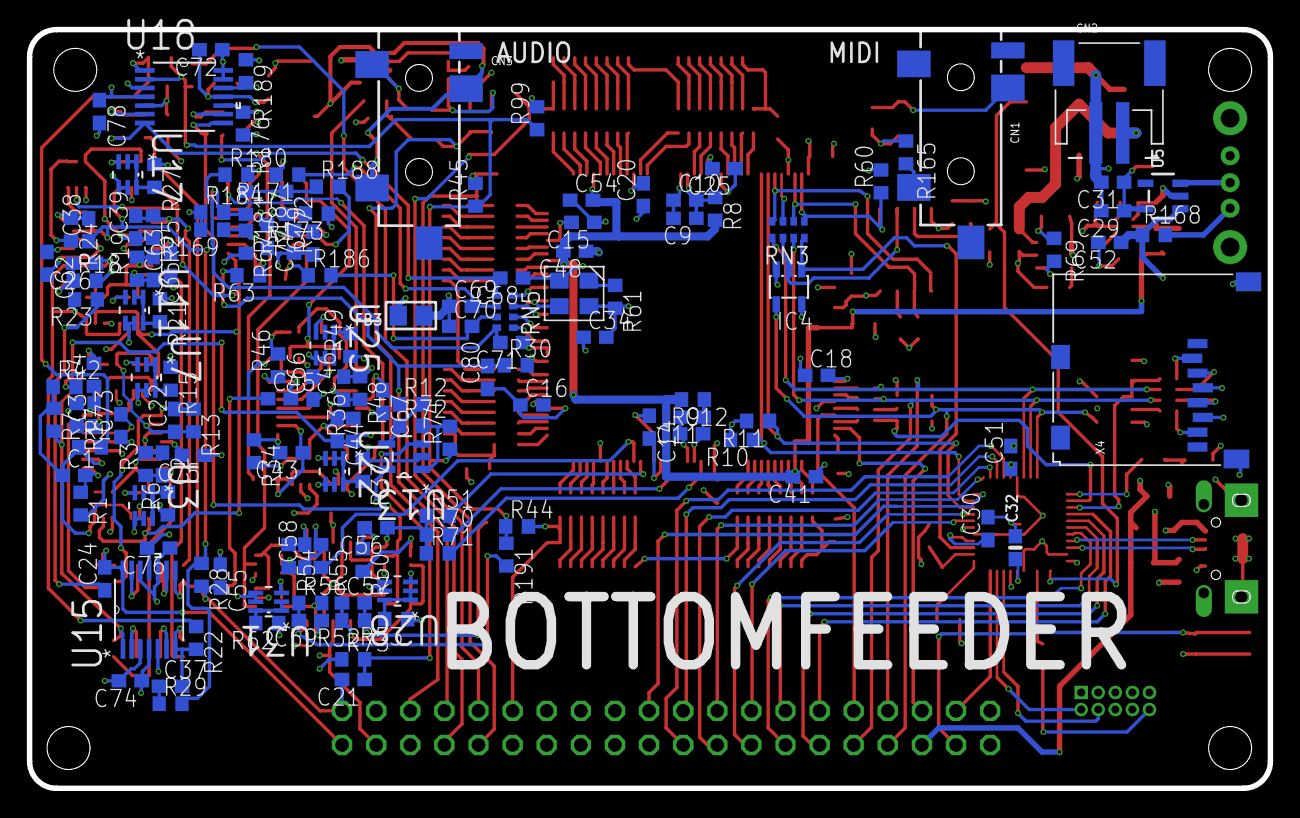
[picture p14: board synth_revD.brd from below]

Board: 4 copper layers, 92.4 x 56.5 mm, 276 parts (146 on the bottom side), 290 nets.

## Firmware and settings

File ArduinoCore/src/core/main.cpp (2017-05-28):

/*
  Copyright (c) 2015 Arduino LLC.  All right reserved.

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
  You should have received a copy of the GNU Lesser General Public
  License along with this library; if not, write to the Free Software
  Foundation, Inc., 51 Franklin St, Fifth Floor, Boston, MA  02110-1301  USA
*/

#define ARDUINO_MAIN
#include "Arduino.h"

// Weak empty variant initialization function.
// May be redefined by variant files.
void initVariant() __attribute__((weak));
void initVariant() { }

// Initialize C library
extern "C" void __libc_init_array(void);

/*
 * \brief Main entry point of Arduino application
 */

/*
#define IS_MTB_ENABLED \
        REG_MTB_MASTER & MTB_MASTER_EN
#define DISABLE_MTB \
        REG_MTB_MASTER = REG_MTB_MASTER & ~MTB_MASTER_EN
#define ENABLE_MTB \
        REG_MTB_MASTER = REG_MTB_MASTER | MTB_MASTER_EN

__attribute__((aligned(1024)))
volatile char __tracebuffer__[1024];
volatile int __tracebuffersize__ = sizeof(__tracebuffer__);
void InitTraceBuffer()
{
    int index = 0;
    uint32_t mtbEnabled = IS_MTB_ENABLED;
    DISABLE_MTB;
    for(index =0; index<1024; index++)
    {
        __tracebuffer__[index];
        __tracebuffersize__;
    }
    if(mtbEnabled)
        ENABLE_MTB;
}
*/

int main( void )

{
  init();

  __libc_init_array();

  initVariant();
  
  //InitTraceBuffer();

  delay(1);
#if defined(USBCON)
  USBDevice.init();
  USBDevice.attach();
#endif

  setup();

  for (;;)
  {
    loop();
    if (serialEventRun) serialEventRun();
  }

  return 0;
}

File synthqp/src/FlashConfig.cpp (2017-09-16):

#include "Arduino.h"			
#include "FlashConfig.h"
#include "SPI.h"

#include "qpcpp.h"
#include "qp_extras.h"
#include "event.h"
#include "waveDefs.h"

Q_DEFINE_THIS_FILE

//#define BFX_DEBUG
#define SD_READ_MAX 256
static byte sdbuf[SD_READ_MAX];

FlashConfig::FlashConfig() :
QActive((QStateHandler)&FlashConfig::InitialPseudoState),
m_id(FLASH_CONFIG), m_name("FLASH_CONFIG"), settings(50000000, MSBFIRST, SPI_MODE0),
SDBuffer(sdbuf, SD_READ_MAX) {}

FlashConfig::~FlashConfig() {}
	
void FlashConfig::Start(uint8_t prio) {
	pinMode(SPI_SS_B, OUTPUT);
	digitalWrite(SPI_SS_B, HIGH);
	
	QActive::start(prio, m_evtQueueStor, ARRAY_COUNT(m_evtQueueStor), NULL, 0);
};

QState FlashConfig::InitialPseudoState(FlashConfig * const me, QEvt const * const e) {
	(void)e;
	
	me->subscribe(FLASH_CONFIG_START_REQ);
	me->subscribe(FLASH_CONFIG_STOP_REQ);
	me->subscribe(FLASH_CONFIG_WRITE_CONFIGURATION);
	me->subscribe(FLASH_CONFIG_VERIFY_CONFIGURATION_REQ);
	
	me->subscribe(FLASH_CONFIG_WRITE_WAVEFORMS_REQ);
	
	me->subscribe(FLASH_CONFIG_READ_LFO_REQ);
	me->subscribe(FLASH_CONFIG_READ_TO_LISTENER_REQ);
	
	me->subscribe(SD_READ_FILE_RESPONSE);
	
	return Q_TRAN(&FlashConfig::Root);
}

QState FlashConfig::Root(FlashConfig * const me, QEvt const * const e) {
	QState status;
	switch (e->sig) {
		case Q_ENTRY_SIG: {
			LOG_EVENT(e);
			status = Q_HANDLED();
			break;
		}
		case Q_EXIT_SIG: {
			LOG_EVENT(e);
			status = Q_HANDLED();
			break;
		}
		case Q_INIT_SIG: {
			status = Q_TRAN(&FlashConfig::Stopped);
			break;
		}
		case FLASH_CONFIG_START_REQ: {
			LOG_EVENT(e);
			Evt const &req = EVT_CAST(*e);
			Evt *evt = new FlashConfigStartCfm(req.GetSeq(), ERROR_STATE);
			QF::PUBLISH(evt, me);
			status = Q_HANDLED();
			break;
		}
		default: {
			status = Q_SUPER(&QHsm::top);
			break;
		}
	}
	return status;
}

QState FlashConfig::Stopped(FlashConfig * const me, QEvt const * const e) {
	QState status;
	switch (e->sig) {
		case Q_ENTRY_SIG: {
			LOG_EVENT(e);
			status = Q_HANDLED();
			break;
		}
		case Q_EXIT_SIG: {
			LOG_EVENT(e);
			status = Q_HANDLED();
			break;
		}
		case FLASH_CONFIG_STOP_REQ: {
			LOG_EVENT(e);
			Evt const &req = EVT_CAST(*e);
			Evt *evt = new FlashConfigStopCfm(req.GetSeq(), ERROR_SUCCESS);
			QF::PUBLISH(evt, me);
			status = Q_HANDLED();
			break;
		}
		case FLASH_CONFIG_START_REQ: {
			LOG_EVENT(e);
			SPI.begin();
			
			if(me->flash_read_id()){
				Evt const &req = EVT_CAST(*e);
				Evt *evt = new FlashConfigStartCfm(req.GetSeq(), ERROR_SUCCESS);
				QF::PUBLISH(evt, me);
				status = Q_TRAN(&FlashConfig::Started);
			}
			else{
				//TODO: fail here
				__BKPT();
			}
			break;
		}
		default: {
			status = Q_SUPER(&FlashConfig::Root);
			break;
		}
	}
	return status;
}
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

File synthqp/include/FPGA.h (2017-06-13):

#ifndef LIB_FPGA_H_
#define LIB_FPGA_H_

#include <inttypes.h>
#include "qpcpp.h"
#include "qp_extras.h"
#include "Arduino.h"
#include "SPI.h"

#include "buffer.h"
#include "hsm_id.h"

#define CRESET_B        A3
#define CDONE           A4

#define FPGA_CS			10

#define FPGA_CLKFREQ 150000000
#define FPGA_N 1024

#define DATA_LENGTH (4096)

#define FPGA_REG_MASK(reg) (reg & 0xFF) << 6

#define FPGA_W0_FREQ 0x00
#define FPGA_W1_FREQ 0x01
#define FPGA_W2_FREQ 0x02

#define FPGA_PWM0 0x03 //cutoff
#define FPGA_PWM1 0x04 //reso
#define FPGA_PWM2 0x05 //noise
#define FPGA_PWM3 0x06 //vca
#define FPGA_PWM4 0x07 //sub

#define FPGA_VOL 0x08
#define FPGA_ENABLE 0x09

#define FPGA_A_INTERVAL_HIGH 0x0a
#define FPGA_A_INTERVAL_LOW 0x0b
#define FPGA_D_INTERVAL_HIGH 0x0c
#define FPGA_D_INTERVAL_LOW 0x0d
#define FPGA_R_INTERVAL_HIGH 0x0e
#define FPGA_R_INTERVAL_LOW 0x0f
#define FPGA_SUS_LEVEL 0x10
#define FPGA_ENV0_PWM0_MUL 0x11
#define FPGA_ENV0_PWM2_MUL 0x12

#define FPGA_PORT		0x13

#define FPGA_KEY_PRESSED 0x14

#define FPGA_SUB_OFF 0x00
#define FPGA_SUB0 0x01
#define FPGA_SUB1 0x02
#define FPGA_SUB2 0x04

#define FPGA_RW_BIT(bit) (bit << 15)

#define FPGA_VOL_MASK(num)	(0x7 << (uint16_t)(3 * (num - 1)))
#define FPGA_VOL_BITS(num, vol)	((vol & 0x7) << (uint16_t)(3 * (num - 1)))

#define FPGA_WRITE_ENABLE_MASK	0x70
#define FPGA_WRITE_ENABLE_CHANNEL(num) (1 << (num + 4))
#define FPGA_WRITE_ENABLE_BIT	0x80

#define FPGA_KEY_PRESSED_BIT 0x100

using namespace QP;
using namespace FW;

class FPGA : public QActive {
	
public:
	FPGA();
	~FPGA();
	
	void Start(uint8_t prio);
	
	protected:
	static QState InitialPseudoState(FPGA * const me, QEvt const * const e);
	static QState Root(FPGA * const me, QEvt const * const e);
	static QState Stopped(FPGA * const me, QEvt const * const e);
	static QState Started(FPGA * const me, QEvt const * const e);
	static QState WritingWave(FPGA * const me, QEvt const * const e);
	
	enum {
		EVT_QUEUE_COUNT = 32,
		DEFER_QUEUE_COUNT = 16
	};
	QEvt const *m_evtQueueStor[EVT_QUEUE_COUNT];
	QEvt const *m_deferQueueStor[DEFER_QUEUE_COUNT];
	QEQueue m_deferQueue;
	uint8_t m_id;
	char const * m_name;
	
private:

	void writeReg(uint8_t reg, uint16_t value);
	uint16_t readReg(uint8_t reg);
	
	SPISettings settings;
	
	//for writing waves
	uint8_t writeChannel;
	uint8_t writeNum;
	
	QTimeEvt m_startTimer;
};

#endif

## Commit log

2017-05-23 added saving and loading presets, fixed bugs
    [FPGA.cpp, FlashConfig.cpp, MIDIUART.h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]
2017-06-13 removed captouch, fixed some bugs, fixed reso scaling
    [FPGA.cpp, FPGA.h, MIDIUart.cpp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]
2017-07-25 DM: not sure
    [synth_revC.brd, synth_revC.sch]
2017-09-16 added missing stuff
    [synth_revD.brd, synth_revD.sch]
2018-07-01 add pdf schematic and update readme

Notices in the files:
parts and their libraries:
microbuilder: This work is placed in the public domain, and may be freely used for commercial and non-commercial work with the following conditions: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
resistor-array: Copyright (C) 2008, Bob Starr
